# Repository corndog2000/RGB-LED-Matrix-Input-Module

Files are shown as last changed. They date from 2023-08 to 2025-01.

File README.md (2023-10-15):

# RGB-LED-Matrix-Input-Module

# Please check this project's license. It uses a Attribution-NonCommercial-ShareAlike 4.0 International license.

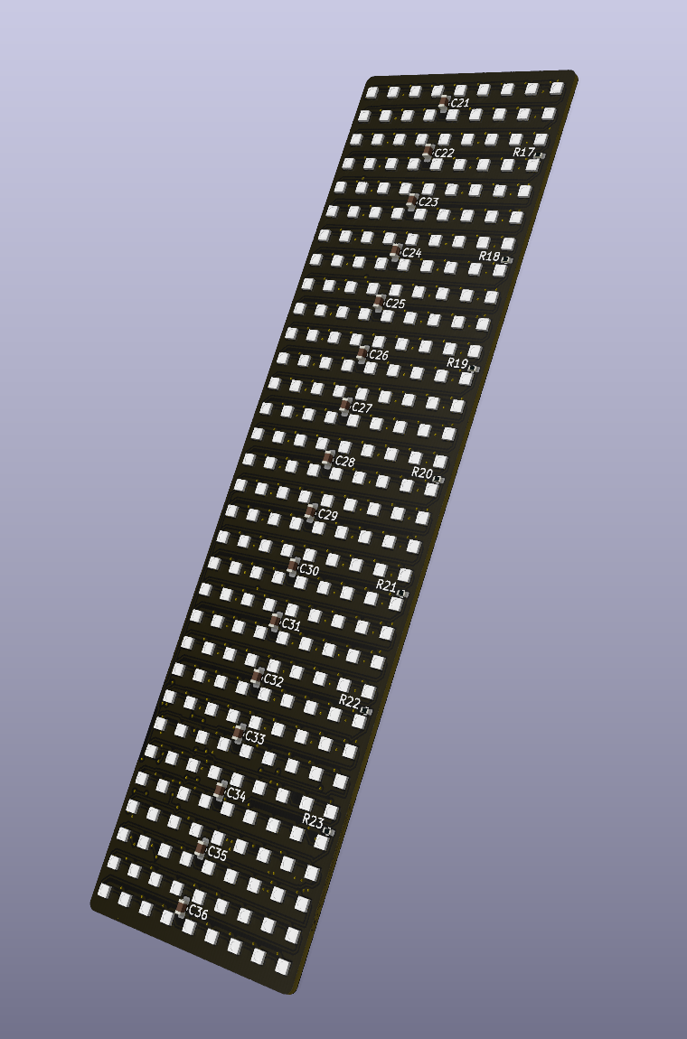
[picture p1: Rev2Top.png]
Rev 2 3D render front

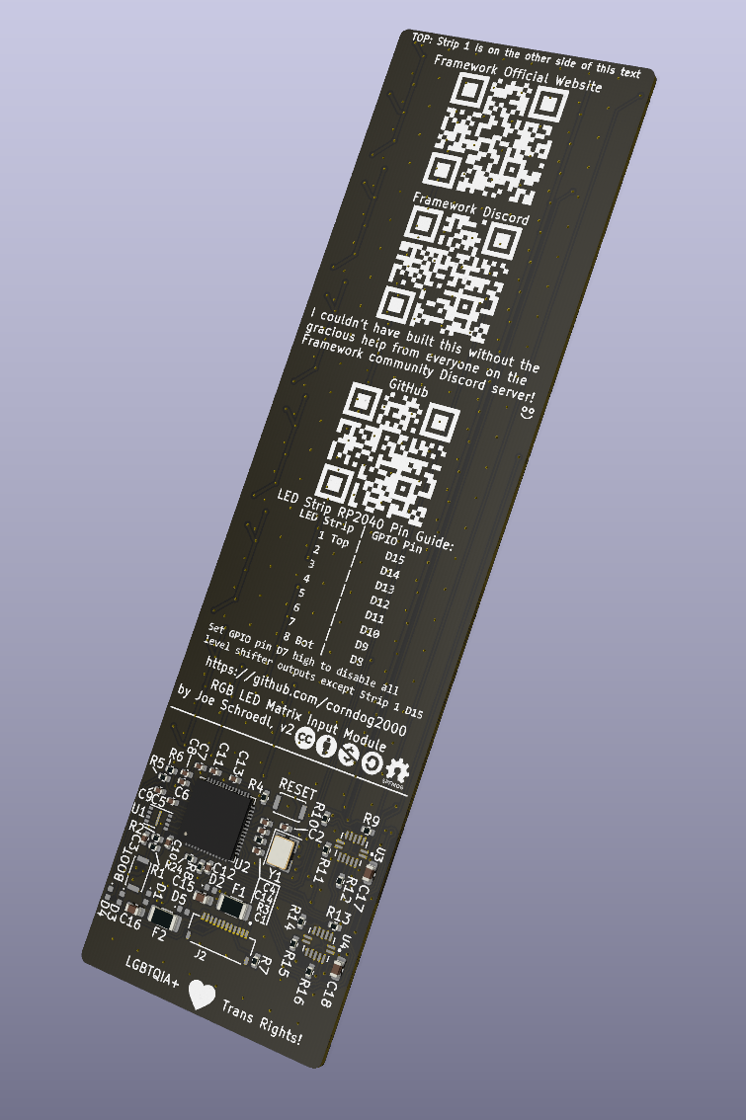
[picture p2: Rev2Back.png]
Rev 2 3D render back


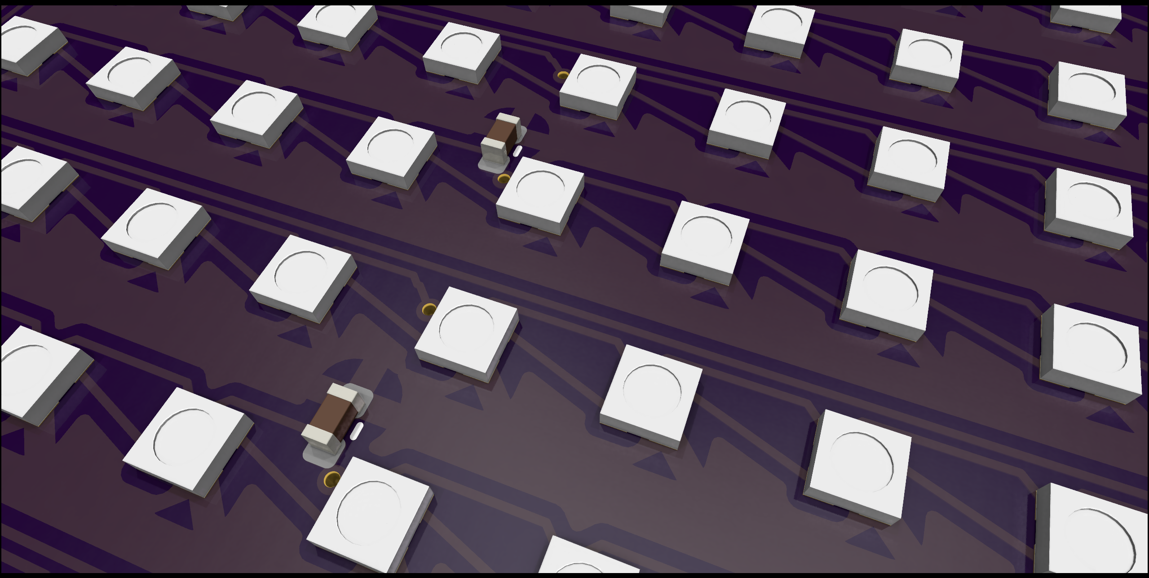
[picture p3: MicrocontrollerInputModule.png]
Close up of the LED Matrix PCB 3D render


Framework Forum Post

Video Demo

Watch the video (https://www.youtube.com/embed/vBwoF8WDbUY)

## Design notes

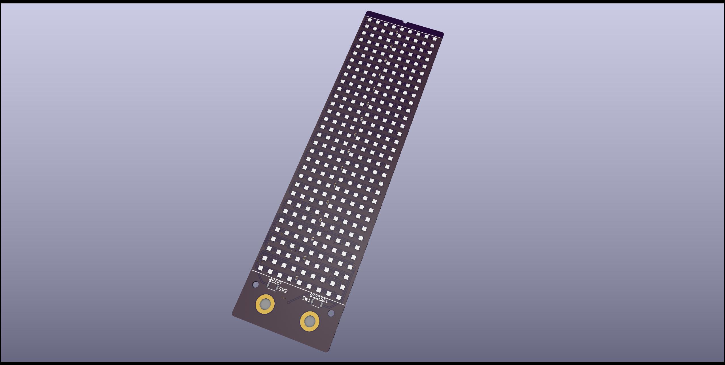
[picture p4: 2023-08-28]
MicrocontrollerInputModule.jpg

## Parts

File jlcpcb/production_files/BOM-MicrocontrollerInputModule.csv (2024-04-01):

Comment | Designator | Footprint | LCSC
1k | R1,R3 | R_0402_1005Metric | C106235
27 | R5,R6 | R_0402_1005Metric | C138021
180k | R7 | R_0402_1005Metric | C138046
100nF | C10,C11,C12,C13,C14,C3,C4,C5,C7,C9 | C_0402_1005Metric | C1525
10uF | C15,C16,C17,C18 | C_0603_1608Metric | C19702
RP2040 | U2 | QFN-56-1EP_7x7mm_P0.4mm_EP3.2x3.2mm | C2040
A6H-2101 | SW1 | SW_A6H-2101_OMR | C224990
470 | R10,R11,R12,R13,R14,R15,R16,R9 | R_0402_1005Metric | C25117
W25Q16JVUXIQ | U1 | SON-8-1EP_3x2mm_P0.5mm_EP0.2x1.6mm | C2843335
SK6805-EC14 | N1,N10,N100,N101,N102,N103,N104,N105,N106,N107,N108,N109,N11,N110,N111,N112,N113,N114,N115,N116,N117,N118,N119,N12,N120,N121,N122,N123,N124,N125,N126,N127,N128,N129,N13,N130,N131,N132,N133,N134,N135,N136,N137,N138,N139,N14,N140,N141,N142,N143,N144,N145,N146,N147,N148,N149,N15,N150,N151,N152,N153,N154,N155,N156,N157,N158,N159,N16,N160,N161,N162,N163,N164,N165,N166,N167,N168,N169,N17,N170,N171,N172,N173,N174,N175,N176,N177,N178,N179,N18,N180,N181,N182,N183,N184,N185,N186,N187,N188,N189,N19,N190,N191,N192,N193,N194,N195,N196,N197,N198,N199,N2,N20,N200,N201,N202,N203,N204,N205,N206,N207,N208,N209,N21,N210,N211,N212,N213,N214,N215,N216,N217,N218,N219,N22,N220,N221,N222,N223,N224,N225,N226,N227,N228,N229,N23,N230,N231,N232,N233,N234,N235,N236,N237,N238,N239,N24,N240,N241,N242,N243,N244,N245,N246,N247,N248,N249,N25,N250,N251,N252,N253,N254,N255,N256,N257,N258,N259,N26,N260,N261,N262,N263,N264,N265,N266,N267,N268,N269,N27,N270,N271,N272,N273,N274,N275,N276,N277,N278,N279,N28,N280,N281,N282,N283,N284,N285,N286,N287,N288,N29,N3,N30,N31,N32,N33,N34,N35,N36,N37,N38,N39,N4,N40,N41,N42,N43,N44,N45,N46,N47,N48,N49,N5,N50,N51,N52,N53,N54,N55,N56,N57,N58,N59,N6,N60,N61,N62,N63,N64,N65,N66,N67,N68,N69,N7,N70,N71,N72,N73,N74,N75,N76,N77,N78,N79,N8,N80,N81,N82,N83,N84,N85,N86,N87,N88,N89,N9,N90,N91,N92,N93,N94,N95,N96,N97,N98,N99 | SK6805-EC14 | C2909055
1uF | C6,C8 | C_0402_1005Metric | C29266
FH34SRJ-12S-0.5SH_50_ | J2 | HRS_FH34SRJ-12S-0.5SH_50_ | C424659
D_TVS | D1,D2,D3,D4,D5 | D_0402_1005Metric | C468904
74AHC125BQ_115 | U3,U4 | QFN50P300X250X100-15N | C554218
10k | R2,R24,R4,R8 | R_0402_1005Metric | C60490
12.000MHz | Y1 | Crystal_SMD_3225-4Pin_3.2x2.5mm | C7294551
15pF | C1,C2 | C_0402_1005Metric | C76950
Polyfuse 600mA | F1 | R_1206_3216Metric | C883122
Polyfuse 200mA | F2 | R_1206_3216Metric | C910826

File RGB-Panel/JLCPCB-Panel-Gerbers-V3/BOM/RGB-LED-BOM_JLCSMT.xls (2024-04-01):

Comment | Designator | Footprint | LCSC Part Number
100nF | C3, C3, C4, C4, C5, C5, C7, C7, C9, C9, C10, C10, C11, C11, C12, C12, C13, C13, C14, C14 | C_0402_1005Metric | C1525
10uF | C15, C15, C16, C16, C17, C17, C18, C18 | C_0603_1608Metric | C19702
15pF | C1, C1, C2, C2 | C_0402_1005Metric | C76950
1uF | C6, C6, C8, C8 | C_0402_1005Metric | C29266
470 Ohm | R9, R9, R10, R10, R11, R11, R12, R12, R13, R13, R14, R14, R15, R15, R16, R16 | R_0402_1005Metric | C25117
10k Ohm | R2, R2, R4, R4, R8, R8, R24, R24 | R_0402_1005Metric | C60490
1k Ohm | R1, R1, R3, R3 | R_0402_1005Metric | C106235
27 Ohm | R5, R5, R6, R6 | R_0402_1005Metric | C138021
180k Ohm | R7, R7 | R_0402_1005Metric | C138046
D_TVS | D1, D1, D2, D2, D3, D3, D4, D4, D5, D5 | D_0402_1005Metric | C468904
74AHC125BQ_115 | U3, U3, U4, U4 | QFN50P300X250X100-15N | C554218
W25Q16JVUXIQ | U1, U1 | SON-8-1EP_3x2mm_P0.5mm_EP0.2x1.6mm | C2843335
RP2040 | U2, U2 | QFN-56-1EP_7x7mm_P0.4mm_EP3.2x3.2mm | C2040
12.000MHz | Y1, Y1 | Crystal_SMD_3225-4Pin_3.2x2.5mm | C7294551
Polyfuse 600mA | F1, F1 | R_1206_3216Metric | C883122
Polyfuse 200mA | F2, F2 | R_1206_3216Metric | C910826
A6H-2101 | SW1, SW1 | SW_A6H-2101_OMR | C224990
SK6805-EC14 | N1, N1, N2, N2, N3, N3, N4, N4, N5, N5, N6, N6, N7, N7, N8, N8, N9, N9, N10, N10, N11, N11, N12, N12, N13, N13, N14, N14, N15, N15, N16, N16, N17, N17, N18, N18, N19, N19, N20, N20, N21, N21, N22, N22, N23, N23, N24, N24, N25, N25, N26, N26, N27, N27, N28, N28, N29, N29, N30, N30, N31, N31, N32, N32, N33, N33, N34, N34, N35, N35, N36, N36, N37, N37, N38, N38, N39, N39, N40, N40, N41, N41, N42, N42, N43, N43, N44, N44, N45, N45, N46, N46, N47, N47, N48, N48, N49, N49, N50, N50, N51, N51, N52, N52, N53, N53, N54, N54, N55, N55, N56, N56, N57, N57, N58, N58, N59, N59, N60, N60, N61, N61, N62, N62, N63, N63, N64, N64, N65, N65, N66, N66, N67, N67, N68, N68, N69, N69, N70, N70, N71, N71, N72, N72, N73, N73, N74, N74, N75, N75, N76, N76, N77, N77, N78, N78, N79, N79, N80, N80, N81, N81, N82, N82, N83, N83, N84, N84, N85, N85, N86, N86, N87, N87, N88, N88, N89, N89, N90, N90, N91, N91, N92, N92, N93, N93, N94, N94, N95, N95, N96, N96, N97, N97, N98, N98, N99, N99, N100, N100, N101, N101, N102, N102, N103, N103, N104, N104, N105, N105, N106, N106, N107, N107, N108, N108, N109, N109, N110, N110, N111, N111, N112, N112, N113, N113, N114, N114, N115, N115, N116, N116, N117, N117, N118, N118, N119, N119, N120, N120, N121, N121, N122, N122, N123, N123, N124, N124, N125, N125, N126, N126, N127, N127, N128, N128, N129, N129, N130, N130, N131, N131, N132, N132, N133, N133, N134, N134, N135, N135, N136, N136, N137, N137, N138, N138, N139, N139, N140, N140, N141, N141, N142, N142, N143, N143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 | SMD,1.4x1.4mm | C2909055
FH34SRJ-12S-0.5SH_50_ | J2, J2 | HRS_FH34SRJ-12S-0.5SH_50_ | C424659
Fiducial | KiKit_FID_B_1 | Fiducial
Fiducial | KiKit_FID_B_2 | Fiducial
Fiducial | KiKit_FID_B_3 | Fiducial
Fiducial | KiKit_FID_B_4 | Fiducial
Fiducial | KiKit_FID_T_1 | Fiducial
Fiducial | KiKit_FID_T_2 | Fiducial
Fiducial | KiKit_FID_T_3 | Fiducial
Fiducial | KiKit_FID_T_4 | Fiducial
NPTH | KiKit_TO_1 | NPTH
NPTH | KiKit_TO_2 | NPTH
NPTH | KiKit_TO_3 | NPTH
NPTH | KiKit_TO_4 | NPTH

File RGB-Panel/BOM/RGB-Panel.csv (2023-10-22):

Id | Designator | Footprint | Quantity | Designation | Supplier and ref
1 | C2,C1,C1,C2 | C_0402_1005Metric | 4 | 15pF
2 | F1,F1 | R_1206_3216Metric | 2 | Polyfuse 600mA
3 | R6,R6,R5,R5 | R_0402_1005Metric | 4 | 27
4 | C5,C9,C11,C9,C11,C10,C7,C4,C14,C13,C3,C12,C12,C4,C10,C7,C14,C13,C3,C5 | C_0402_1005Metric | 20 | 100nF
5 | U4,U3,U4,U3 | QFN50P300X250X100-15N | 4 | 74AHC125BQ_115
6 | R7,R7 | R_0402_1005Metric | 2 | 180k
7 | D5,D2,D2,D4,D1,D3,D3,D5,D1,D4 | D_0402_1005Metric | 10 | D_TVS
8 | C15,C18,C17,C16,C16,C15,C18,C17,C26,C33,C35,C22,C32,C24,C30,C34,C21,C28,C27,C29,C30,C23,C36,C34,C22,C25,C23,C31,C29,C24,C35,C26,C28,C32,C21,C27,C36,C25,C31,C33 | C_0603_1608Metric | 40 | 10uF
9 | KiKit_FID_B_2,KiKit_FID_B_1,KiKit_FID_B_3,KiKit_FID_B_4,KiKit_FID_T_3,KiKit_FID_T_1,KiKit_FID_T_2,KiKit_FID_T_4 | Fiducial | 8 | Fiducial
10 | SW1,SW1 | SW_A6H-2101_OMR | 2 | A6H-2101
11 | C8,C6,C6,C8 | C_0402_1005Metric | 4 | 1uF
12 | Y1,Y1 | Crystal_SMD_3225-4Pin_3.2x2.5mm | 2 | 12.000MHz
13 | F2,F2 | R_1206_3216Metric | 2 | Polyfuse 200mA
14 | U2,U2 | QFN-56-1EP_7x7mm_P0.4mm_EP3.2x3.2mm | 2 | RP2040
15 | J2,J2 | HRS_FH34SRJ-12S-0.5SH_50_ | 2 | FH34SRJ-12S-0.5SH_50_
16 | R3,R3,R1,R1 | R_0402_1005Metric | 4 | 1k
17 | U1,U1 | SON-8-1EP_3x2mm_P0.5mm_EP0.2x1.6mm | 2 | W25Q16JVUXIQ
18 | N121,N31,N122,N137,N257,N236,N151,N4,N38,N98,N156,N68,N286,N81,N83,N28,N120,N67,N141,N149,N273,N259,N128,N219,N59,N172,N261,N127,N49,N51,N223,N40,N58,N181,N210,N52,N268,N119,N280,N85,N154,N54,N120,N65,N210,N50,N110,N235,N284,N109,N165,N254,N78,N271,N193,N132,N69,N267,N190,N216,N257,N248,N54,N21,N7,N1,N188,N224,N248,N3,N247,N221,N126,N57,N72,N148,N195,N272,N31,N17,N169,N115,N274,N113,N194,N203,N256,N92,N91,N14,N251,N220,N89,N95,N100,N253,N110,N104,N19,N146,N131,N260,N232,N247,N228,N80,N215,N2,N77,N3,N189,N259,N25,N212,N96,N41,N246,N21,N151,N180,N156,N102,N9,N202,N287,N9,N53,N232,N265,N103,N105,N75,N262,N158,N106,N174,N240,N246,N233,N119,N233,N271,N264,N252,N160,N118,N55,N124,N36,N212,N13,N145,N47,N111,N244,N26,N276,N66,N136,N61,N51,N220,N45,N164,N187,N126,N27,N107,N186,N278,N114,N189,N153,N33,N221,N8,N273,N135,N181,N199,N173,N14,N88,N92,N176,N178,N71,N144,N200,N207,N191,N125,N280,N20,N227,N215,N216,N254,N108,N266,N32,N60,N150,N162,N168,N93,N159,N95,N197,N88,N79,N22,N186,N38,N90,N285,N223,N242,N104,N281,N39,N7,N93,N30,N103,N238,N237,N40,N67,N90,N185,N24,N238,N282,N143,N72,N79,N179,N227,N191,N5,N146,N214,N263,N243,N264,N239,N117,N171,N124,N276,N184,N22,N89,N161,N147,N15,N243,N169,N148,N91,N99,N116,N59,N76,N206,N263,N10,N27,N207,N36,N144,N145,N106,N63,N64,N222,N139,N60,N226,N47,N204,N205,N163,N269,N43,N287,N278,N64,N112,N43,N244,N234,N153,N174,N84,N44,N108,N11,N185,N99,N44,N5,N149,N190,N283,N134,N48,N63,N270,N198,N35,N118,N231,N48,N245,N42,N139,N25,N33,N155,N177,N133,N52,N46,N2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 | SK6805-EC14 | 576 | ~
19 | KiKit_MB_41_1,KiKit_MB_15_4,KiKit_MB_48_5,KiKit_MB_2_4,KiKit_MB_38_4,KiKit_MB_48_4,KiKit_MB_10_1,KiKit_MB_46_1,KiKit_MB_20_1,KiKit_MB_41_2,KiKit_MB_21_3,KiKit_MB_45_6,KiKit_MB_10_2,KiKit_MB_8_1,KiKit_MB_9_1,KiKit_MB_36_4,KiKit_MB_46_4,KiKit_MB_30_1,KiKit_MB_9_3,KiKit_MB_42_2,KiKit_MB_28_1,KiKit_MB_24_3,KiKit_MB_14_2,KiKit_TO_2,KiKit_MB_27_2,KiKit_MB_30_3,KiKit_MB_23_4,KiKit_MB_35_2,KiKit_MB_33_4,KiKit_MB_37_1,KiKit_MB_46_3,KiKit_MB_42_3,KiKit_MB_40_4,KiKit_MB_33_3,KiKit_MB_28_3,KiKit_MB_44_6,KiKit_MB_48_1,KiKit_MB_32_3,KiKit_MB_13_2,KiKit_MB_27_3,KiKit_MB_11_4,KiKit_MB_44_4,KiKit_MB_48_7,KiKit_MB_42_4,KiKit_TO_1,KiKit_MB_9_4,KiKit_MB_26_2,KiKit_MB_48_3,KiKit_MB_24_2,KiKit_MB_5_2,KiKit_MB_18_3,KiKit_MB_41_3,KiKit_MB_44_5,KiKit_MB_41_5,KiKit_MB_18_4,KiKit_MB_29_4,KiKit_MB_4_1,KiKit_MB_47_5,KiKit_MB_1_4,KiKit_MB_43_4,KiKit_MB_31_3,KiKit_MB_25_3,KiKit_MB_2_2,KiKit_MB_10_4,KiKit_MB_16_1,KiKit_MB_35_3,KiKit_MB_44_3,KiKit_MB_1_2,KiKit_MB_12_3,KiKit_MB_44_7,KiKit_MB_43_2,KiKit_MB_33_1,KiKit_MB_31_2,KiKit_TO_4,KiKit_MB_8_3,KiKit_MB_17_3,KiKit_MB_17_4,KiKit_MB_47_6,KiKit_MB_13_3,KiKit_MB_28_2,KiKit_MB_14_3,KiKit_MB_21_2,KiKit_MB_38_3,KiKit_MB_7_3,KiKit_MB_4_4,KiKit_MB_23_1,KiKit_MB_27_4,KiKit_MB_4_2,KiKit_MB_17_1,KiKit_MB_15_3,KiKit_MB_25_4,KiKit_MB_18_2,KiKit_MB_27_1,KiKit_MB_24_4,KiKit_TO_3,KiKit_MB_14_4,KiKit_MB_37_3,KiKit_MB_46_6,KiKit_MB_47_4,KiKit_MB_3_4,KiKit_MB_20_2,KiKit_MB_46_2,KiKit_MB_14_1,KiKit_MB_42_1,KiKit_MB_22_1,KiKit_MB_39_2,KiKit_MB_31_1,KiKit_MB_30_4,KiKit_MB_42_7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 | NPTH | 220 | NPTH

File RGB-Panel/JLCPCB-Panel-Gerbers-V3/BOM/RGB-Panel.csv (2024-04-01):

Id | Designator | Footprint | Quantity | Designation | Supplier and ref
1 | C15,C15,C16,C17,C18,C16,C17,C18 | C_0603_1608Metric | 8 | 10uF
2 | Y1,Y1 | Crystal_SMD_3225-4Pin_3.2x2.5mm | 2 | 12.000MHz
3 | U4,U4,U3,U3 | QFN50P300X250X100-15N | 4 | 74AHC125BQ_115
4 | F2,F2 | R_1206_3216Metric | 2 | Polyfuse 200mA
5 | R1,R3,R1,R3 | R_0402_1005Metric | 4 | 1k
6 | D2,D1,D3,D2,D3,D5,D4,D4,D1,D5 | D_0402_1005Metric | 10 | D_TVS
7 | R7,R7 | R_0402_1005Metric | 2 | 180k
8 | SW1,SW1 | SW_A6H-2101_OMR | 2 | A6H-2101
9 | J2,J2 | HRS_FH34SRJ-12S-0.5SH_50_ | 2 | FH34SRJ-12S-0.5SH_50_
10 | R5,R6,R6,R5 | R_0402_1005Metric | 4 | 27
11 | C5,C5,C10,C7,C9,C13,C12,C12,C9,C14,C11,C10,C13,C3,C7,C4,C14,C11,C3,C4 | C_0402_1005Metric | 20 | 100nF
12 | C1,C2,C1,C2 | C_0402_1005Metric | 4 | 15pF
13 | U1,U1 | SON-8-1EP_3x2mm_P0.5mm_EP0.2x1.6mm | 2 | W25Q16JVUXIQ
14 | C6,C8,C6,C8 | C_0402_1005Metric | 4 | 1uF
15 | KiKit_FID_B_4,KiKit_FID_B_2,KiKit_FID_B_1,KiKit_FID_B_3,KiKit_FID_T_3,KiKit_FID_T_1,KiKit_FID_T_2,KiKit_FID_T_4 | Fiducial | 8 | Fiducial
16 | U2,U2 | QFN-56-1EP_7x7mm_P0.4mm_EP3.2x3.2mm | 2 | RP2040
17 | F1,F1 | R_1206_3216Metric | 2 | Polyfuse 600mA
18 | N13,N117,N168,N184,N66,N53,N282,N68,N104,N122,N273,N173,N41,N72,N153,N175,N255,N138,N174,N240,N180,N16,N7,N96,N148,N260,N83,N267,N132,N280,N144,N225,N240,N205,N267,N101,N139,N160,N179,N112,N48,N154,N231,N65,N189,N95,N180,N29,N81,N182,N47,N105,N40,N243,N213,N150,N162,N253,N221,N206,N26,N216,N27,N131,N222,N184,N6,N189,N142,N248,N31,N3,N121,N132,N210,N272,N18,N127,N55,N268,N108,N164,N145,N46,N10,N258,N60,N61,N52,N115,N34,N61,N230,N276,N123,N185,N116,N212,N90,N252,N64,N204,N251,N157,N113,N34,N123,N54,N268,N191,N133,N278,N274,N182,N50,N70,N226,N44,N69,N41,N30,N54,N24,N8,N114,N168,N279,N266,N165,N170,N247,N32,N279,N262,N239,N43,N125,N181,N214,N152,N262,N178,N159,N203,N28,N11,N235,N201,N163,N49,N190,N110,N71,N176,N217,N26,N45,N242,N143,N80,N225,N144,N43,N274,N9,N64,N195,N158,N69,N161,N211,N70,N232,N51,N15,N71,N93,N82,N120,N214,N66,N103,N140,N48,N44,N129,N85,N102,N50,N62,N241,N120,N63,N244,N137,N87,N271,N228,N227,N33,N222,N85,N231,N73,N1,N39,N107,N57,N210,N215,N36,N79,N93,N197,N254,N94,N248,N152,N237,N94,N20,N117,N55,N108,N223,N8,N237,N19,N136,N30,N247,N192,N273,N206,N266,N217,N89,N218,N83,N130,N285,N286,N77,N128,N232,N146,N167,N242,N12,N196,N167,N275,N88,N235,N177,N5,N19,N158,N5,N198,N106,N11,N134,N99,N35,N183,N2,N81,N288,N124,N97,N116,N211,N88,N74,N56,N99,N89,N245,N233,N126,N105,N103,N234,N86,N269,N141,N286,N21,N166,N73,N22,N104,N134,N151,N265,N141,N124,N218,N205,N219,N159,N233,N145,N257,N118,N252,N146,N58,N59,N52,N245,N13,N4,N169,N118,N51,N97,N40,N229,N181,N156,N276,N202,N14,N18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 | SK6805-EC14 | 576 | ~
19 | KiKit_MB_13_3,KiKit_MB_31_3,KiKit_MB_15_4,KiKit_MB_38_2,KiKit_MB_19_4,KiKit_MB_40_1,KiKit_MB_47_6,KiKit_MB_39_1,KiKit_MB_8_3,KiKit_MB_4_1,KiKit_MB_8_1,KiKit_MB_21_3,KiKit_MB_40_2,KiKit_MB_43_2,KiKit_MB_41_4,KiKit_MB_9_1,KiKit_MB_43_6,KiKit_MB_4_4,KiKit_MB_12_2,KiKit_MB_44_2,KiKit_TO_1,KiKit_MB_15_3,KiKit_MB_1_3,KiKit_MB_25_3,KiKit_MB_12_1,KiKit_MB_25_1,KiKit_MB_32_2,KiKit_MB_34_1,KiKit_MB_28_2,KiKit_MB_14_1,KiKit_MB_11_4,KiKit_MB_43_4,KiKit_MB_6_4,KiKit_MB_3_3,KiKit_MB_19_1,KiKit_MB_7_1,KiKit_MB_5_1,KiKit_MB_12_4,KiKit_MB_48_6,KiKit_MB_6_3,KiKit_MB_3_4,KiKit_MB_1_4,KiKit_MB_30_2,KiKit_MB_5_4,KiKit_MB_46_1,KiKit_MB_24_3,KiKit_MB_45_3,KiKit_MB_40_3,KiKit_MB_7_2,KiKit_MB_8_4,KiKit_MB_22_1,KiKit_MB_9_3,KiKit_MB_41_2,KiKit_MB_17_1,KiKit_MB_46_7,KiKit_MB_35_1,KiKit_MB_48_1,KiKit_MB_27_2,KiKit_MB_17_3,KiKit_MB_43_3,KiKit_MB_18_4,KiKit_MB_36_3,KiKit_MB_43_1,KiKit_MB_7_4,KiKit_MB_27_1,KiKit_MB_16_4,KiKit_MB_35_3,KiKit_MB_48_3,KiKit_MB_39_2,KiKit_MB_43_5,KiKit_MB_10_4,KiKit_MB_21_2,KiKit_MB_44_6,KiKit_MB_1_1,KiKit_MB_22_3,KiKit_MB_10_1,KiKit_MB_37_1,KiKit_MB_36_2,KiKit_MB_34_4,KiKit_MB_3_1,KiKit_MB_28_4,KiKit_MB_31_2,KiKit_MB_26_1,KiKit_MB_31_4,KiKit_MB_17_4,KiKit_MB_23_2,KiKit_MB_47_7,KiKit_MB_38_1,KiKit_MB_22_2,KiKit_MB_2_4,KiKit_MB_29_2,KiKit_MB_36_1,KiKit_MB_19_2,KiKit_MB_5_3,KiKit_MB_30_1,KiKit_MB_9_4,KiKit_MB_4_3,KiKit_MB_17_2,KiKit_MB_11_3,KiKit_MB_18_2,KiKit_MB_46_6,KiKit_MB_2_2,KiKit_MB_41_3,KiKit_MB_26_2,KiKit_MB_43_7,KiKit_MB_36_4,KiKit_MB_37_2,KiKit_MB_29_3,KiKit_MB_42_2,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 | NPTH | 220 | NPTH
20 | ,,,,, |  | 6

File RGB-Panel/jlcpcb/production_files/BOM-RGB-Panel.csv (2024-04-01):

Comment | Designator | Footprint | LCSC
1k | R1-0,R1-1,R3-0,R3-1 | R_0402_1005Metric | C106235
27 | R5-0,R5-1,R6-0,R6-1 | R_0402_1005Metric | C138021
180k | R7-0,R7-1 | R_0402_1005Metric | C138046
100nF | C10-0,C10-1,C11-0,C11-1,C12-0,C12-1,C13-0,C13-1,C14-0,C14-1,C3-0,C3-1,C4-0,C4-1,C5-0,C5-1,C7-0,C7-1,C9-0,C9-1 | C_0402_1005Metric | C1525
10uF | C15-0,C15-1,C16-0,C16-1,C17-0,C17-1,C18-0,C18-1 | C_0603_1608Metric | C19702
RP2040 | U2-0,U2-1 | QFN-56-1EP_7x7mm_P0.4mm_EP3.2x3.2mm | C2040
A6H-2101 | SW1-0,SW1-1 | SW_A6H-2101_OMR | C224990
470 | R10-0,R10-1,R11-0,R11-1,R12-0,R12-1,R13-0,R13-1,R14-0,R14-1,R15-0,R15-1,R16-0,R16-1,R9-0,R9-1 | R_0402_1005Metric | C25117
W25Q16JVUXIQ | U1-0,U1-1 | SON-8-1EP_3x2mm_P0.5mm_EP0.2x1.6mm | C2843335
SK6805-EC14 | N1-0,N1-1,N10-0,N10-1,N100-0,N100-1,N101-0,N101-1,N102-0,N102-1,N103-0,N103-1,N104-0,N104-1,N105-0,N105-1,N106-0,N106-1,N107-0,N107-1,N108-0,N108-1,N109-0,N109-1,N11-0,N11-1,N110-0,N110-1,N111-0,N111-1,N112-0,N112-1,N113-0,N113-1,N114-0,N114-1,N115-0,N115-1,N116-0,N116-1,N117-0,N117-1,N118-0,N118-1,N119-0,N119-1,N12-0,N12-1,N120-0,N120-1,N121-0,N121-1,N122-0,N122-1,N123-0,N123-1,N124-0,N124-1,N125-0,N125-1,N126-0,N126-1,N127-0,N127-1,N128-0,N128-1,N129-0,N129-1,N13-0,N13-1,N130-0,N130-1,N131-0,N131-1,N132-0,N132-1,N133-0,N133-1,N134-0,N134-1,N135-0,N135-1,N136-0,N136-1,N137-0,N137-1,N138-0,N138-1,N139-0,N139-1,N14-0,N14-1,N140-0,N140-1,N141-0,N141-1,N142-0,N142-1,N143-0,N143-1,N144-0,N144-1,N145-0,N145-1,N146-0,N146-1,N147-0,N147-1,N148-0,N148-1,N149-0,N149-1,N15-0,N15-1,N150-0,N150-1,N151-0,N151-1,N152-0,N152-1,N153-0,N153-1,N154-0,N154-1,N155-0,N155-1,N156-0,N156-1,N157-0,N157-1,N158-0,N158-1,N159-0,N159-1,N16-0,N16-1,N160-0,N160-1,N161-0,N161-1,N162-0,N162-1,N163-0,N163-1,N164-0,N164-1,N165-0,N165-1,N166-0,N166-1,N167-0,N167-1,N168-0,N168-1,N169-0,N169-1,N17-0,N17-1,N170-0,N170-1,N171-0,N171-1,N172-0,N172-1,N173-0,N173-1,N174-0,N174-1,N175-0,N175-1,N176-0,N176-1,N177-0,N177-1,N178-0,N178-1,N179-0,N179-1,N18-0,N18-1,N180-0,N180-1,N181-0,N181-1,N182-0,N182-1,N183-0,N183-1,N184-0,N184-1,N185-0,N185-1,N186-0,N186-1,N187-0,N187-1,N188-0,N188-1,N189-0,N189-1,N19-0,N19-1,N190-0,N190-1,N191-0,N191-1,N192-0,N192-1,N193-0,N193-1,N194-0,N194-1,N195-0,N195-1,N196-0,N196-1,N197-0,N19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 | SK6805-EC14 | C2909055
1uF | C6-0,C6-1,C8-0,C8-1 | C_0402_1005Metric | C29266
FH34SRJ-12S-0.5SH_50_ | J2-0,J2-1 | HRS_FH34SRJ-12S-0.5SH_50_ | C424659
D_TVS | D1-0,D1-1,D2-0,D2-1,D3-0,D3-1,D4-0,D4-1,D5-0,D5-1 | D_0402_1005Metric | C468904
74AHC125BQ_115 | U3-0,U3-1,U4-0,U4-1 | QFN50P300X250X100-15N | C554218
10k | R2-0,R2-1,R24-0,R24-1,R4-0,R4-1,R8-0,R8-1 | R_0402_1005Metric | C60490
12.000MHz | Y1-0,Y1-1 | Crystal_SMD_3225-4Pin_3.2x2.5mm | C7294551
15pF | C1-0,C1-1,C2-0,C2-1 | C_0402_1005Metric | C76950
Polyfuse 600mA | F1-0,F1-1 | R_1206_3216Metric | C883122
Polyfuse 200mA | F2-0,F2-1 | R_1206_3216Metric | C910826
Fiducial | KiKit_FID_B_4 | Fiducial
Fiducial | KiKit_FID_B_2 | Fiducial
Fiducial | KiKit_FID_B_3 | Fiducial
Fiducial | KiKit_FID_B_1 | Fiducial
NPTH | KiKit_MB_48_6 | NPTH
NPTH | KiKit_MB_32_2 | NPTH
NPTH | KiKit_MB_34_2 | NPTH
NPTH | KiKit_MB_27_2 | NPTH
NPTH | KiKit_MB_39_2 | NPTH
NPTH | KiKit_MB_46_7 | NPTH
NPTH | KiKit_MB_34_4 | NPTH
NPTH | KiKit_MB_37_4 | NPTH
NPTH | KiKit_MB_25_1 | NPTH
NPTH | KiKit_MB_45_5 | NPTH
NPTH | KiKit_MB_38_4 | NPTH
NPTH | KiKit_MB_41_1 | NPTH
NPTH | KiKit_MB_36_1 | NPTH
NPTH | KiKit_MB_33_4 | NPTH
NPTH | KiKit_MB_48_2 | NPTH
NPTH | KiKit_MB_12_4 | NPTH
Fiducial | KiKit_FID_T_3 | Fiducial
NPTH | KiKit_MB_25_4 | NPTH
NPTH | KiKit_MB_40_4 | NPTH
NPTH | KiKit_MB_48_7 | NPTH
NPTH | KiKit_MB_23_2 | NPTH
NPTH | KiKit_MB_21_2 | NPTH
NPTH | KiKit_MB_5_4 | NPTH
NPTH | KiKit_TO_3 | NPTH
NPTH | KiKit_MB_9_3 | NPTH
NPTH | KiKit_MB_3_1 | NPTH
NPTH | KiKit_MB_36_3 | NPTH
NPTH | KiKit_MB_21_1 | NPTH
NPTH | KiKit_MB_43_3 | NPTH
NPTH | KiKit_MB_41_3 | NPTH
NPTH | KiKit_MB_14_3 | NPTH
NPTH | KiKit_MB_16_2 | NPTH
NPTH | KiKit_MB_20_1 | NPTH
NPTH | KiKit_MB_29_2 | NPTH
NPTH | KiKit_MB_17_2 | NPTH
NPTH | KiKit_MB_38_2 | NPTH
NPTH | KiKit_MB_10_1 | NPTH
NPTH | KiKit_MB_47_4 | NPTH
NPTH | KiKit_MB_45_7 | NPTH
NPTH | KiKit_MB_46_5 | NPTH
NPTH | KiKit_MB_4_3 | NPTH
NPTH | KiKit_MB_23_4 | NPTH
NPTH | KiKit_MB_23_1 | NPTH
NPTH | KiKit_MB_8_1 | NPTH
NPTH | KiKit_MB_39_3 | NPTH
NPTH | KiKit_MB_42_2 | NPTH
NPTH | KiKit_MB_5_3 | NPTH
NPTH | KiKit_MB_42_4 | NPTH
NPTH | KiKit_MB_43_4 | NPTH
Fiducial | KiKit_FID_T_1 | Fiducial
NPTH | KiKit_MB_24_3 | NPTH
NPTH | KiKit_MB_14_4 | NPTH
NPTH | KiKit_MB_25_3 | NPTH
NPTH | KiKit_MB_46_2 | NPTH
NPTH | KiKit_MB_26_1 | NPTH
NPTH | KiKit_MB_5_1 | NPTH
NPTH | KiKit_MB_4_4 | NPTH
NPTH | KiKit_MB_7_1 | NPTH
NPTH | KiKit_MB_44_3 | NPTH
NPTH | KiKit_MB_31_2 | NPTH
NPTH | KiKit_MB_31_1 | NPTH
NPTH | KiKit_MB_27_3 | NPTH
NPTH | KiKit_MB_10_3 | NPTH
NPTH | KiKit_MB_4_2 | NPTH
NPTH | KiKit_MB_19_1 | NPTH
NPTH | KiKit_MB_12_2 | NPTH
NPTH | KiKit_MB_13_1 | NPTH
NPTH | KiKit_MB_3_4 | NPTH
NPTH | KiKit_MB_23_3 | NPTH
NPTH | KiKit_MB_48_4 | NPTH
NPTH | KiKit_MB_47_1 | NPTH
NPTH | KiKit_MB_35_3 | NPTH
NPTH | KiKit_MB_38_1 | NPTH
NPTH | KiKit_MB_34_1 | NPTH
NPTH | KiKit_MB_24_1 | NPTH
NPTH | KiKit_MB_44_1 | NPTH
NPTH | KiKit_TO_1 | NPTH
NPTH | KiKit_MB_20_2 | NPTH
NPTH | KiKit_MB_47_2 | NPTH
NPTH | KiKit_MB_10_4 | NPTH
NPTH | KiKit_MB_24_2 | NPTH
NPTH | KiKit_MB_6_2 | NPTH
NPTH | KiKit_MB_28_2 | NPTH
NPTH | KiKit_MB_41_5 | NPTH
NPTH | KiKit_MB_11_3 | NPTH
NPTH | KiKit_MB_32_3 | NPTH
NPTH | KiKit_MB_42_3 | NPTH
NPTH | KiKit_MB_28_4 | NPTH
NPTH | KiKit_MB_15_4 | NPTH
NPTH | KiKit_MB_41_4 | NPTH
NPTH | KiKit_MB_37_3 | NPTH
NPTH | KiKit_MB_29_1 | NPTH
NPTH | KiKit_MB_17_1 | NPTH
NPTH | KiKit_MB_12_3 | NPTH
NPTH | KiKit_MB_45_6 | NPTH
NPTH | KiKit_MB_43_6 | NPTH
NPTH | KiKit_MB_15_1 | NPTH
NPTH | KiKit_MB_47_6 | NPTH
NPTH | KiKit_MB_45_2 | NPTH
NPTH | KiKit_MB_1_4 | NPTH
NPTH | KiKit_MB_7_4 | NPTH
NPTH | KiKit_MB_47_5 | NPTH
NPTH | KiKit_MB_31_3 | NPTH
NPTH | KiKit_MB_26_2 | NPTH
NPTH | KiKit_MB_26_3 | NPTH
NPTH | KiKit_MB_3_3 | NPTH
NPTH | KiKit_MB_2_4 | NPTH
NPTH | KiKit_MB_35_4 | NPTH
NPTH | KiKit_MB_42_1 | NPTH
NPTH | KiKit_MB_44_2 | NPTH
NPTH | KiKit_MB_9_4 | NPTH
NPTH | KiKit_MB_10_2 | NPTH
NPTH | KiKit_MB_42_7 | NPTH
NPTH | KiKit_MB_18_1 | NPTH
NPTH | KiKit_MB_31_4 | NPTH
NPTH | KiKit_MB_7_3 | NPTH
NPTH | KiKit_TO_2 | NPTH
NPTH | KiKit_MB_47_7 | NPTH
NPTH | KiKit_MB_43_2 | NPTH
NPTH | KiKit_MB_43_7 | NPTH
NPTH | KiKit_MB_29_4 | NPTH
NPTH | KiKit_MB_3_2 | NPTH
NPTH | KiKit_MB_35_2 | NPTH
NPTH | KiKit_MB_18_2 | NPTH
NPTH | KiKit_MB_26_4 | NPTH
NPTH | KiKit_MB_39_1 | NPTH
NPTH | KiKit_MB_35_1 | NPTH
NPTH | KiKit_MB_33_1 | NPTH
NPTH | KiKit_MB_41_2 | NPTH
NPTH | KiKit_MB_29_3 | NPTH
NPTH | KiKit_MB_40_1 | NPTH
NPTH | KiKit_MB_40_2 | NPTH
NPTH | KiKit_MB_28_3 | NPTH
NPTH | KiKit_MB_1_3 | NPTH
NPTH | KiKit_MB_33_3 | NPTH
NPTH | KiKit_MB_2_3 | NPTH
NPTH | KiKit_MB_22_4 | NPTH
NPTH | KiKit_MB_30_3 | NPTH
NPTH | KiKit_MB_44_4 | NPTH
NPTH | KiKit_MB_8_4 | NPTH
Fiducial | KiKit_FID_T_4 | Fiducial
NPTH | KiKit_MB_14_2 | NPTH
NPTH | KiKit_MB_47_3 | NPTH
NPTH | KiKit_MB_42_6 | NPTH
NPTH | KiKit_MB_16_3 | NPTH
NPTH | KiKit_MB_44_7 | NPTH
NPTH | KiKit_MB_16_1 | NPTH
NPTH | KiKit_MB_24_4 | NPTH
NPTH | KiKit_MB_36_2 | NPTH
NPTH | KiKit_MB_46_4 | NPTH
NPTH | KiKit_MB_17_4 | NPTH
NPTH | KiKit_MB_13_2 | NPTH
NPTH | KiKit_MB_30_4 | NPTH
NPTH | KiKit_MB_30_2 | NPTH
NPTH | KiKit_MB_9_2 | NPTH
NPTH | KiKit_MB_2_2 | NPTH
NPTH | KiKit_MB_11_2 | NPTH
NPTH | KiKit_TO_4 | NPTH
NPTH | KiKit_MB_13_3 | NPTH
NPTH | KiKit_MB_27_4 | NPTH
NPTH | KiKit_MB_22_3 | NPTH
NPTH | KiKit_MB_30_1 | NPTH
Fiducial | KiKit_FID_T_2 | Fiducial
NPTH | KiKit_MB_6_4 | NPTH
NPTH | KiKit_MB_20_4 | NPTH
NPTH | KiKit_MB_19_3 | NPTH
NPTH | KiKit_MB_19_4 | NPTH
NPTH | KiKit_MB_1_2 | NPTH
NPTH | KiKit_MB_21_3 | NPTH
NPTH | KiKit_MB_37_2 | NPTH
NPTH | KiKit_MB_18_3 | NPTH
NPTH | KiKit_MB_19_2 | NPTH
NPTH | KiKit_MB_6_3 | NPTH
NPTH | KiKit_MB_48_1 | NPTH
NPTH | KiKit_MB_43_1 | NPTH
NPTH | KiKit_MB_8_3 | NPTH
NPTH | KiKit_MB_43_5 | NPTH
NPTH | KiKit_MB_39_4 | NPTH
NPTH | KiKit_MB_11_4 | NPTH
NPTH | KiKit_MB_41_7 | NPTH
NPTH | KiKit_MB_14_1 | NPTH
NPTH | KiKit_MB_17_3 | NPTH
NPTH | KiKit_MB_32_1 | NPTH
NPTH | KiKit_MB_16_4 | NPTH
NPTH | KiKit_MB_28_1 | NPTH
NPTH | KiKit_MB_15_2 | NPTH
NPTH | KiKit_MB_42_5 | NPTH
NPTH | KiKit_MB_36_4 | NPTH
NPTH | KiKit_MB_21_4 | NPTH
NPTH | KiKit_MB_32_4 | NPTH
NPTH | KiKit_MB_6_1 | NPTH
NPTH | KiKit_MB_8_2 | NPTH
NPTH | KiKit_MB_46_6 | NPTH
NPTH | KiKit_MB_37_1 | NPTH
NPTH | KiKit_MB_20_3 | NPTH
NPTH | KiKit_MB_45_4 | NPTH
NPTH | KiKit_MB_48_5 | NPTH
NPTH | KiKit_MB_1_1 | NPTH
NPTH | KiKit_MB_27_1 | NPTH
NPTH | KiKit_MB_2_1 | NPTH
NPTH | KiKit_MB_11_1 | NPTH
NPTH | KiKit_MB_5_2 | NPTH
NPTH | KiKit_MB_9_1 | NPTH
NPTH | KiKit_MB_46_3 | NPTH
NPTH | KiKit_MB_34_3 | NPTH
NPTH | KiKit_MB_38_3 | NPTH
NPTH | KiKit_MB_22_1 | NPTH
NPTH | KiKit_MB_15_3 | NPTH
NPTH | KiKit_MB_25_2 | NPTH
NPTH | KiKit_MB_13_4 | NPTH
NPTH | KiKit_MB_48_3 | NPTH
NPTH | KiKit_MB_22_2 | NPTH
NPTH | KiKit_MB_40_3 | NPTH
NPTH | KiKit_MB_12_1 | NPTH
NPTH | KiKit_MB_41_6 | NPTH
NPTH | KiKit_MB_44_5 | NPTH
NPTH | KiKit_MB_4_1 | NPTH
NPTH | KiKit_MB_45_1 | NPTH
NPTH | KiKit_MB_46_1 | NPTH
NPTH | KiKit_MB_44_6 | NPTH
NPTH | KiKit_MB_18_4 | NPTH
NPTH | KiKit_MB_45_3 | NPTH
NPTH | KiKit_MB_33_2 | NPTH
NPTH | KiKit_MB_7_2 | NPTH

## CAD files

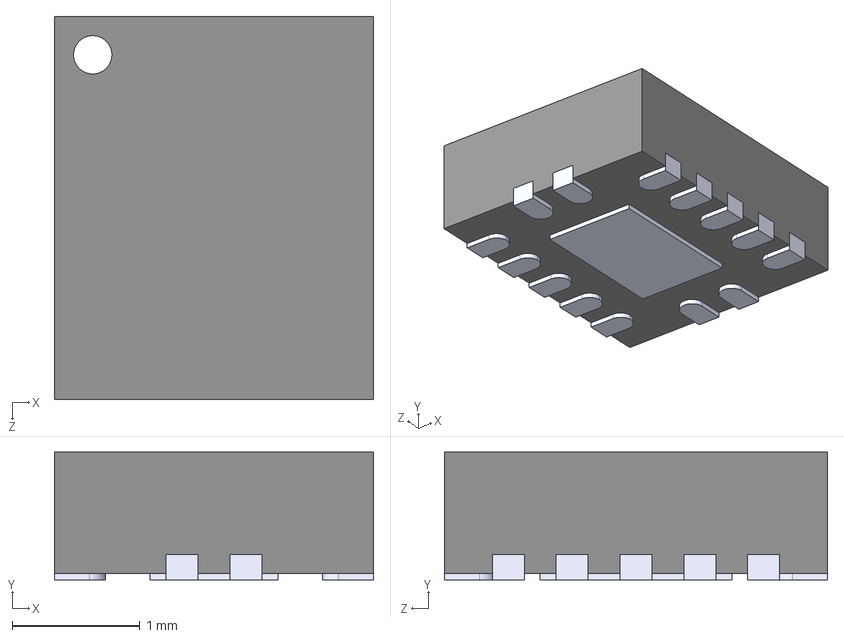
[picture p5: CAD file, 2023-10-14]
Footprint Downloads/74AHC125BQ_115/74AHC125BQ_115.step
2.50 x 1.00 x 3.00 mm

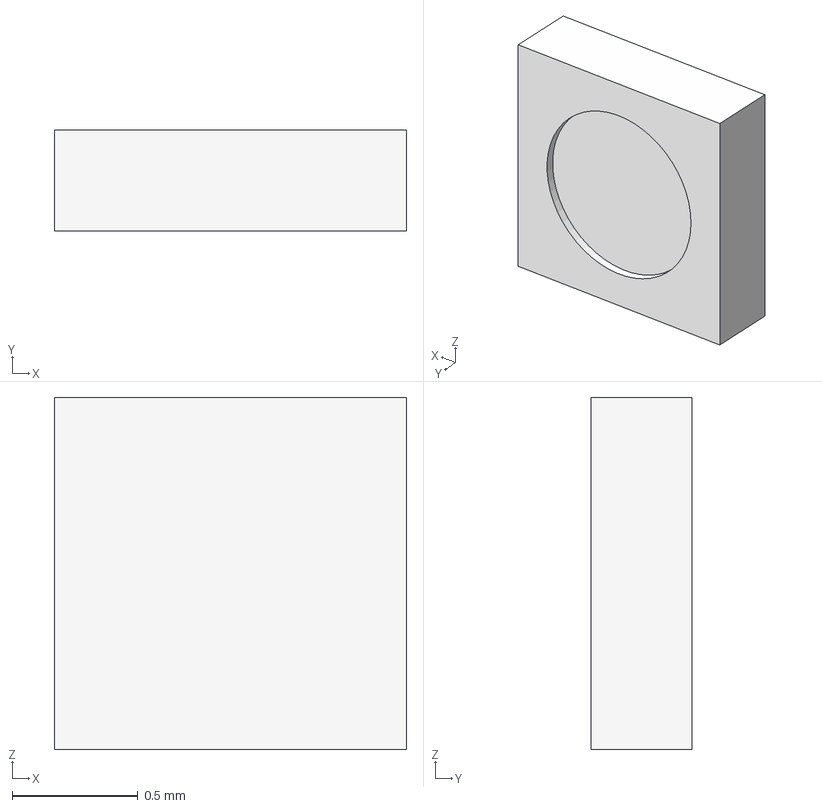
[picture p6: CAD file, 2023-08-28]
LED Model.stp
1.40 x 0.4 x 1.40 mm

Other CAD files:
LED Model.stl

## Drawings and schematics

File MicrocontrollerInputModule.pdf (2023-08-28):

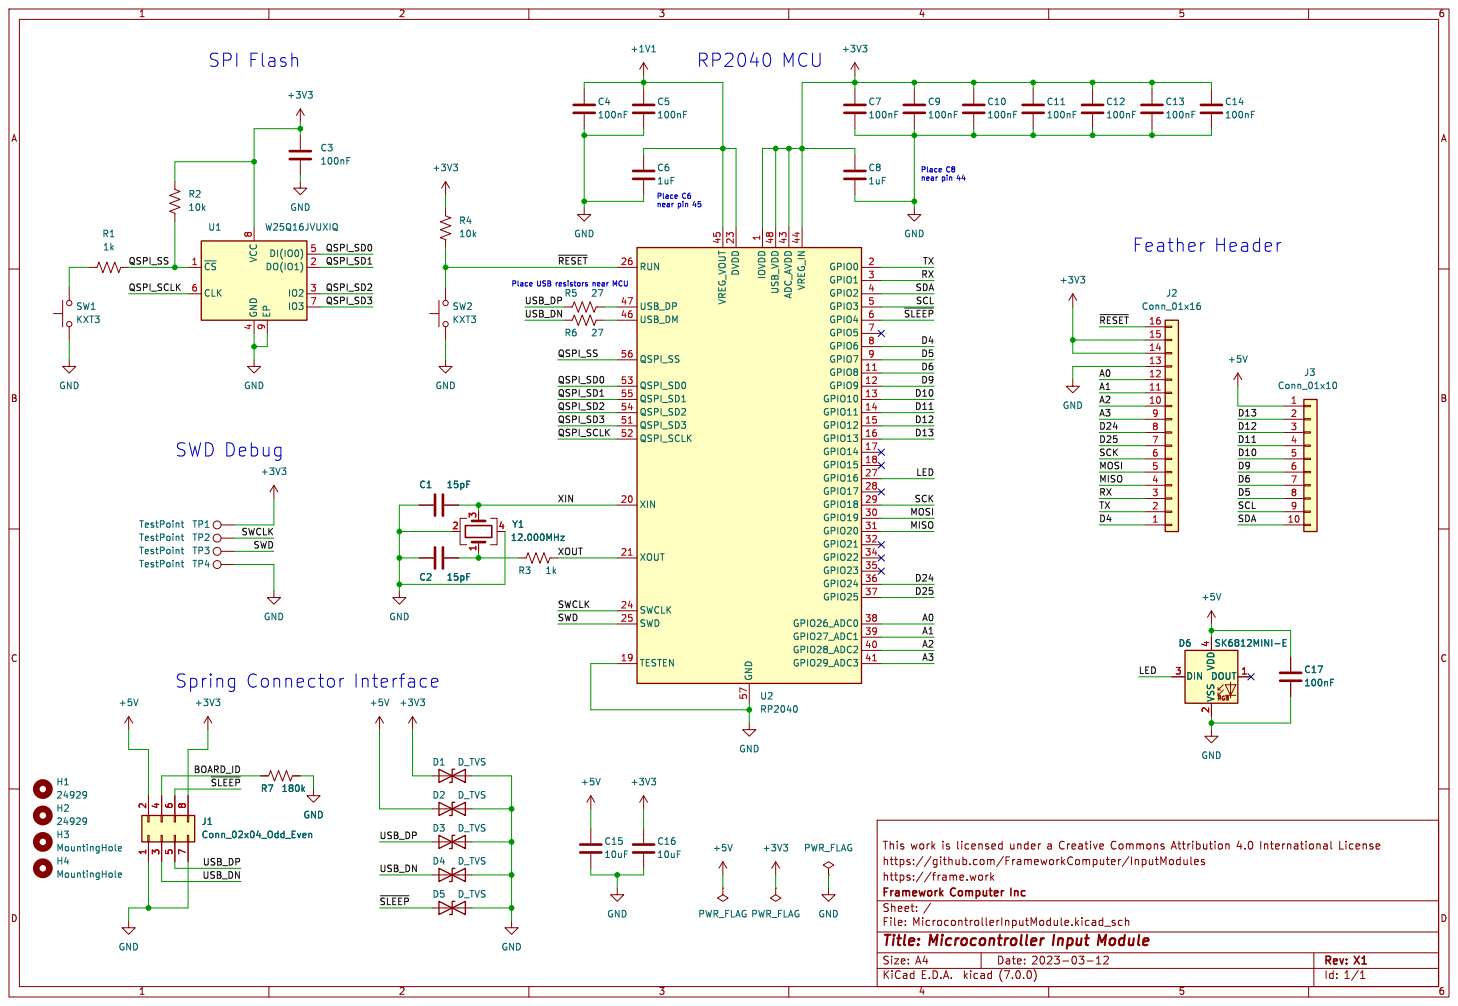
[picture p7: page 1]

1 GPIO8 11 GPIO9 12 GPIO10 13 GPIO11 14 GPIO12 15 GPIO13 16 GPIO14 17 GPIO15 18 TESTEN 19 GPIO0 2 XIN 20 XOUT 21 DVDD 23 SWCLK 24 SWD 25 RUN 26 GPIO16 27 GPIO17 28 GPIO18 29 GPIO1 3 GPIO19 30 GPIO20 31 GPIO21 32 GPIO22 34 GPIO23 35 GPIO24 36 GPIO25 37 GPIO26_ADC0 38 GPIO27_ADC1 39 GPIO2 4 GPIO28_ADC2 40 GPIO29_ADC3 41 ADC_AVDD 43 VREG_IN 44 VREG_VOUT 45 USB_DM 46 USB_DP 47 USB_VDD 48 GPIO3 5 QSPI_SD3 51 QSPI_SCLK 52 QSPI_SD0 53 QSPI_SD2 54 QSPI_SD1 55 QSPI_SS 56 GND 57 GPIO4 6 GPIO5 7 GPIO6 8 GPIO7 9 U2 RP2040 +5V +3V3 GND PWR_FLAG PWR_FLAG

Id: 1/1 Title: Microcontroller Input Module

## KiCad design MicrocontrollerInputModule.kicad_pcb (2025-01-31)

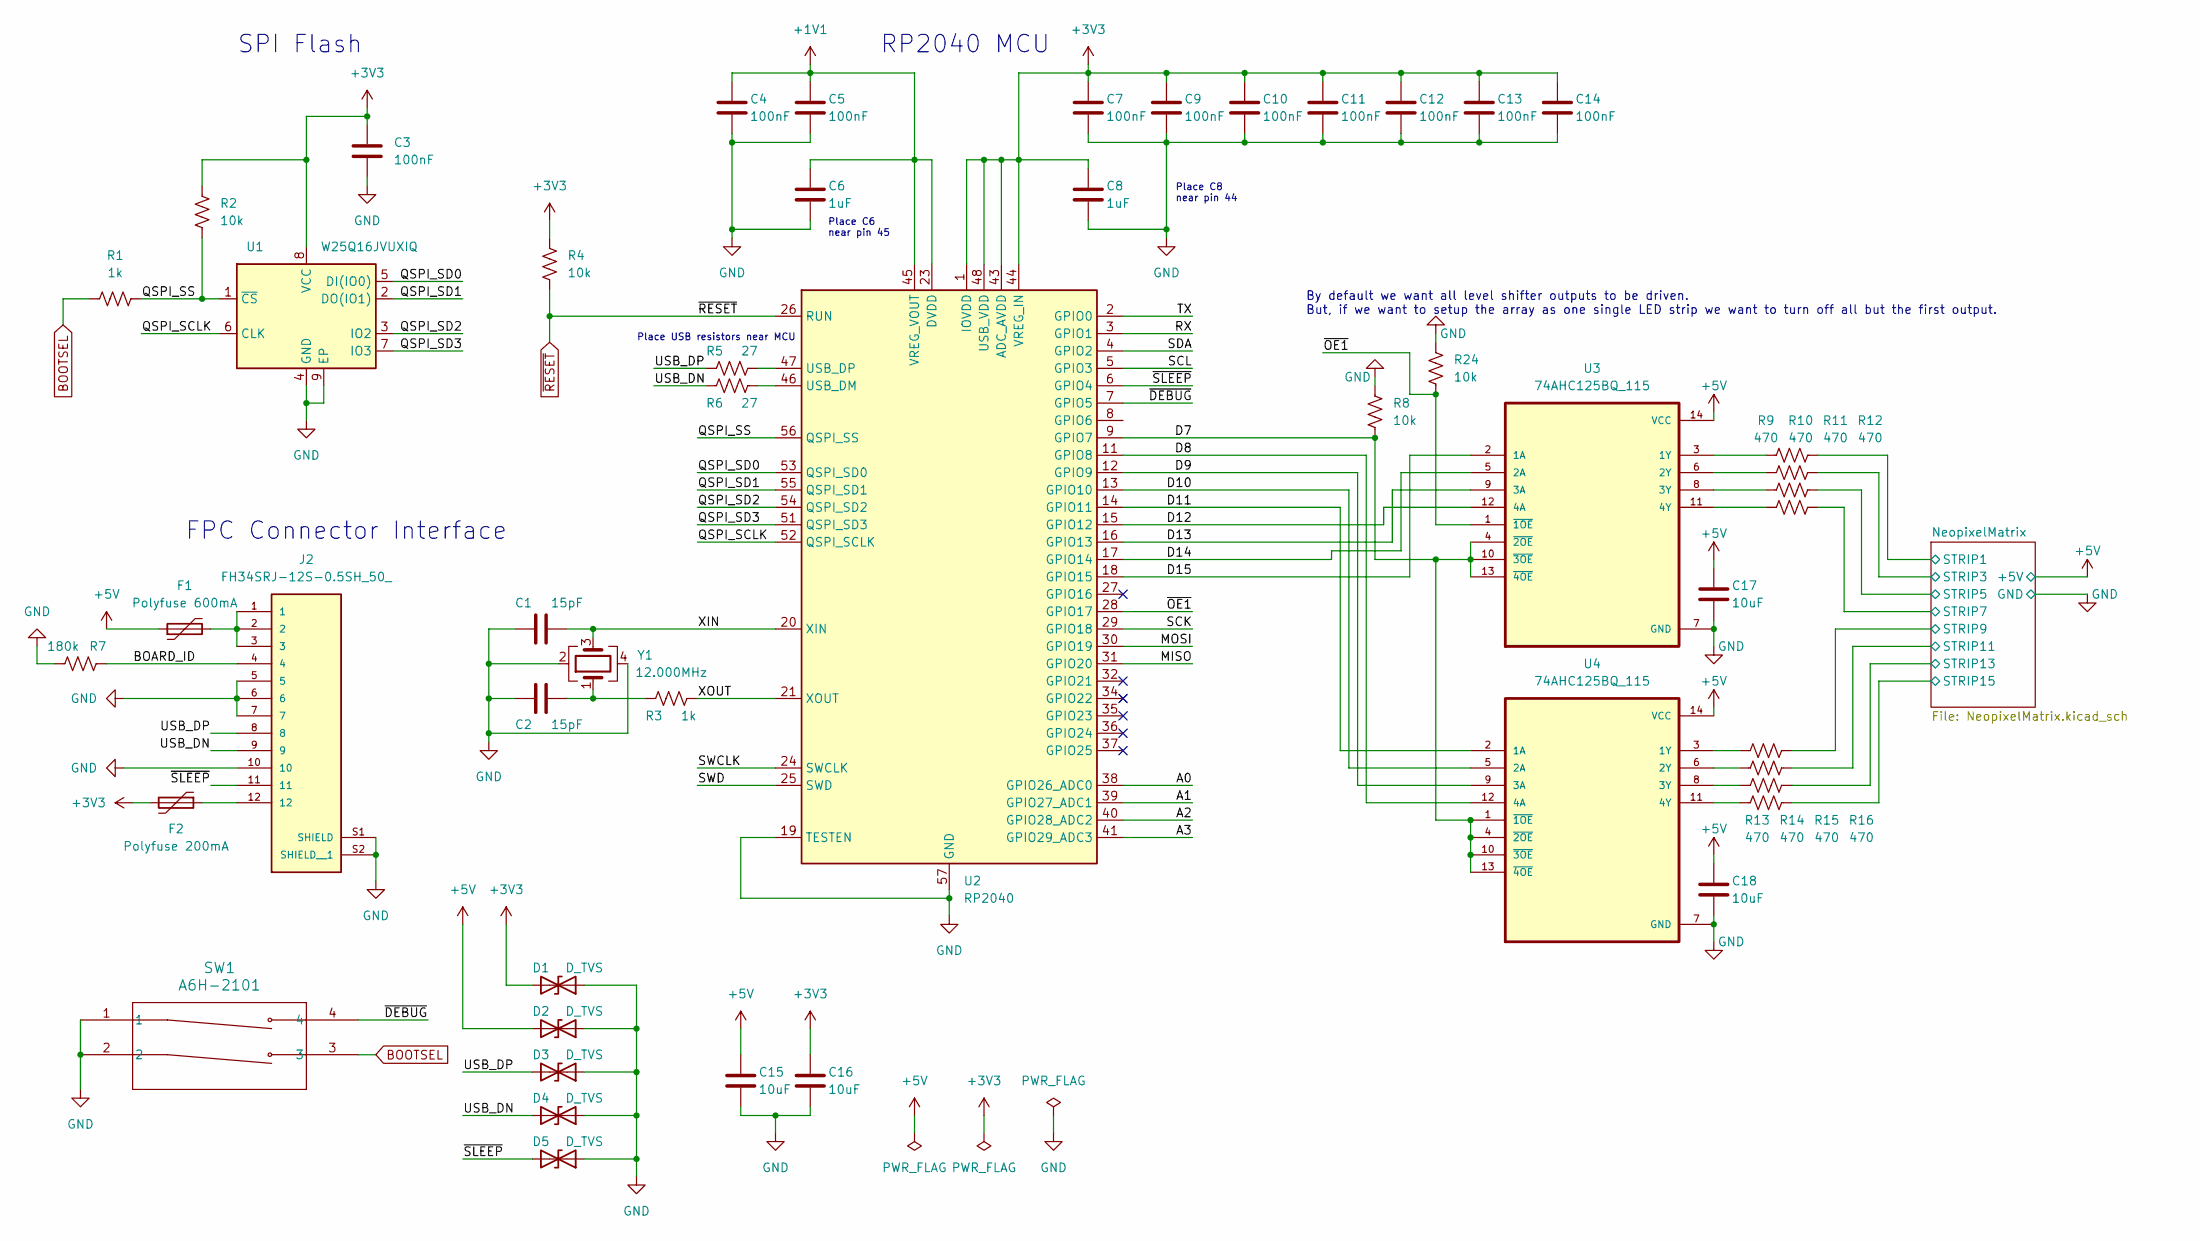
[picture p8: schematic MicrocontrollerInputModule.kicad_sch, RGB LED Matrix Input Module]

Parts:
C1, C2: 15pF; C_0402_1005Metric; LCSC Part # C76950
C3, C4, C5, C7, C9, C10, C11, C12, C13, C14: 100nF; C_0402_1005Metric; LCSC Part # C1525
C6, C8: 1uF; C_0402_1005Metric; LCSC Part # C29266
C15, C16, C17, C18: 10uF; C_0603_1608Metric; LCSC Part # C19702
D1, D2, D3, D4, D5: D_TVS; D_0402_1005Metric; LCSC Part # C468904
F1: Polyfuse 600mA; R_1206_3216Metric; LCSC Part # C883122
F2: Polyfuse 200mA; R_1206_3216Metric; LCSC Part # C910826
J2: FH34SRJ-12S-0.5SH_50_; HRS_FH34SRJ-12S-0.5SH_50_; LCSC Part # C424659
R1, R3: 1k; R_0402_1005Metric; LCSC Part # C106235
R2, R4, R8, R24: 10k; R_0402_1005Metric; LCSC Part # C60490
R5, R6: 27; R_0402_1005Metric; LCSC Part # C138021
R7: 180k; R_0402_1005Metric; LCSC Part # C138046
R9, R10, R11, R12, R13, R14, R15, R16: 470; R_0402_1005Metric; LCSC Part # C25117
SW1: A6H-2101; SW_A6H-2101_OMR; LCSC Part # C224990
U1: W25Q16JVUXIQ; SON-8-1EP_3x2mm_P0.5mm_EP0.2x1.6mm; LCSC Part # C2843335
U2: RP2040; QFN-56-1EP_7x7mm_P0.4mm_EP3.2x3.2mm; LCSC Part # C2040
U3, U4: 74AHC125BQ_115; QFN50P300X250X100-15N; LCSC Part # C554218
Y1: 12.000MHz; Crystal_SMD_3225-4Pin_3.2x2.5mm; LCSC Part # C7294551

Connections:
+1V1: C4.1, C5.1, C6.1, U2.23 (DVDD), U2.45 (VREG_VOUT), U2.50 (DVDD)
+3V3: C3.1, C7.1, C8.1, C9.1, C10.1, C11.1, C12.1, C13.1, C14.1, C16.1, D1.2 (A2), F2.2, R2.1, R4.1, U1.8 (VCC), U2.1 (IOVDD), U2.10 (IOVDD), U2.22 (IOVDD), U2.33 (IOVDD), U2.42 (IOVDD), U2.43 (ADC_AVDD), U2.44 (VREG_IN), U2.48 (USB_VDD), U2.49 (IOVDD)
+5V: C15.1, C17.1, C18.1, D2.2 (A2), F1.1, U3.14 (VCC), U4.14 (VCC); also elsewhere on the board
/A0: U2.38 (GPIO26_ADC0)
/A1: U2.39 (GPIO27_ADC1)
/A2: U2.40 (GPIO28_ADC2)
/A3: U2.41 (GPIO29_ADC3)
/BOARD_ID: J2.4, R7.1
/D7: R8.2, U2.9 (GPIO7), U3.4 (~2OE), U3.10 (~3OE), U3.13 (~4OE), U4.1 (~1OE), U4.4 (~2OE), U4.10 (~3OE), U4.13 (~4OE)
/D8: U2.11 (GPIO8), U4.12 (4A)
/D9: U2.12 (GPIO9), U4.9 (3A)
/D10: U2.13 (GPIO10), U4.5 (2A)
/D11: U2.14 (GPIO11), U4.2 (1A)
/D12: U2.15 (GPIO12), U3.12 (4A)
/D13: U2.16 (GPIO13), U3.9 (3A)
/D14: U2.17 (GPIO14), U3.5 (2A)
/D15: U2.18 (GPIO15), U3.2 (1A)
/MISO: U2.31 (GPIO20)
/MOSI: U2.30 (GPIO19)
/NeopixelMatrix/STRIP1: R9.2; also elsewhere on the board
/NeopixelMatrix/STRIP3: R10.2; also elsewhere on the board
/NeopixelMatrix/STRIP5: R11.2; also elsewhere on the board
/NeopixelMatrix/STRIP7: R12.2; also elsewhere on the board
/NeopixelMatrix/STRIP9: R13.2; also elsewhere on the board
/NeopixelMatrix/STRIP11: R14.2; also elsewhere on the board
/NeopixelMatrix/STRIP13: R15.2; also elsewhere on the board
/NeopixelMatrix/STRIP15: R16.2; also elsewhere on the board
/QSPI_SCLK: U1.6 (CLK), U2.52 (QSPI_SCLK)
/QSPI_SD0: U1.5 (DI(IO0)), U2.53 (QSPI_SD0)
/QSPI_SD1: U1.2 (DO(IO1)), U2.55 (QSPI_SD1)
/QSPI_SD2: U1.3 (IO2), U2.54 (QSPI_SD2)
/QSPI_SD3: U1.7 (IO3), U2.51 (QSPI_SD3)
/QSPI_SS: R1.2, R2.2, U1.1 (~CS), U2.56 (QSPI_SS)
/RX: U2.3 (GPIO1)
/SCK: U2.29 (GPIO18)
/SCL: U2.5 (GPIO3)
/SDA: U2.4 (GPIO2)
/SWCLK: U2.24 (SWCLK)
/SWD: U2.25 (SWD)
/TX: U2.2 (GPIO0)
/USB_DN: D4.2 (A2), J2.9, R6.1
/USB_DP: D3.2 (A2), J2.8, R5.1
/XIN: C1.2, U2.20 (XIN), Y1.3
/XOUT: R3.2, U2.21 (XOUT)
/~DEBUG: SW1.4, U2.7 (GPIO5)
/~OE1: R24.2, U2.28 (GPIO17), U3.1 (~1OE)
/~SLEEP: D5.2 (A2), J2.11, U2.6 (GPIO4)
BOOTSEL: R1.1, SW1.3
GND: C1.1, C2.1, C3.2, C4.2, C5.2, C6.2, C7.2, C8.2, C9.2, C10.2, C11.2, C12.2, C13.2, C14.2, C15.2, C16.2, C17.2, C18.2, D1.1 (A1), D2.1 (A1), D3.1 (A1), D4.1 (A1), D5.1 (A1), J2.5, J2.6, J2.7, J2.10, J2.S1 (SHIELD), J2.S2 (SHIELD__1), R7.2, R8.1, R24.1, SW1.1, SW1.2, U1.4 (GND), U1.9 (EP), U2.19 (TESTEN), U2.57 (GND), U3.7 (GND), U4.7 (GND), Y1.2, Y1.4; also elsewhere on the board
unnamed: C2.2, R3.1, Y1.1
unnamed: F1.2, J2.1, J2.2, J2.3
unnamed: F2.1, J2.12
unnamed: R6.2, U2.46 (USB_DM)
unnamed: R5.2, U2.47 (USB_DP)
unnamed: R9.1, U3.3 (1Y)
unnamed: R10.1, U3.6 (2Y)
unnamed: R11.1, U3.8 (3Y)
unnamed: R12.1, U3.11 (4Y)
unnamed: R13.1, U4.3 (1Y)
unnamed: R14.1, U4.6 (2Y)
unnamed: R15.1, U4.8 (3Y)
unnamed: R16.1, U4.11 (4Y)
~RESET: R4.2, U2.26 (RUN)

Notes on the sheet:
By default we want all level shifter outputs to be driven. But, if we want to setup the array as one single LED strip we want to turn off all but the first output.
SPI Flash
Place C8 near pin 44
Place USB resistors near MCU
Place C6 near pin 45
FPC Connector Interface
RP2040 MCU

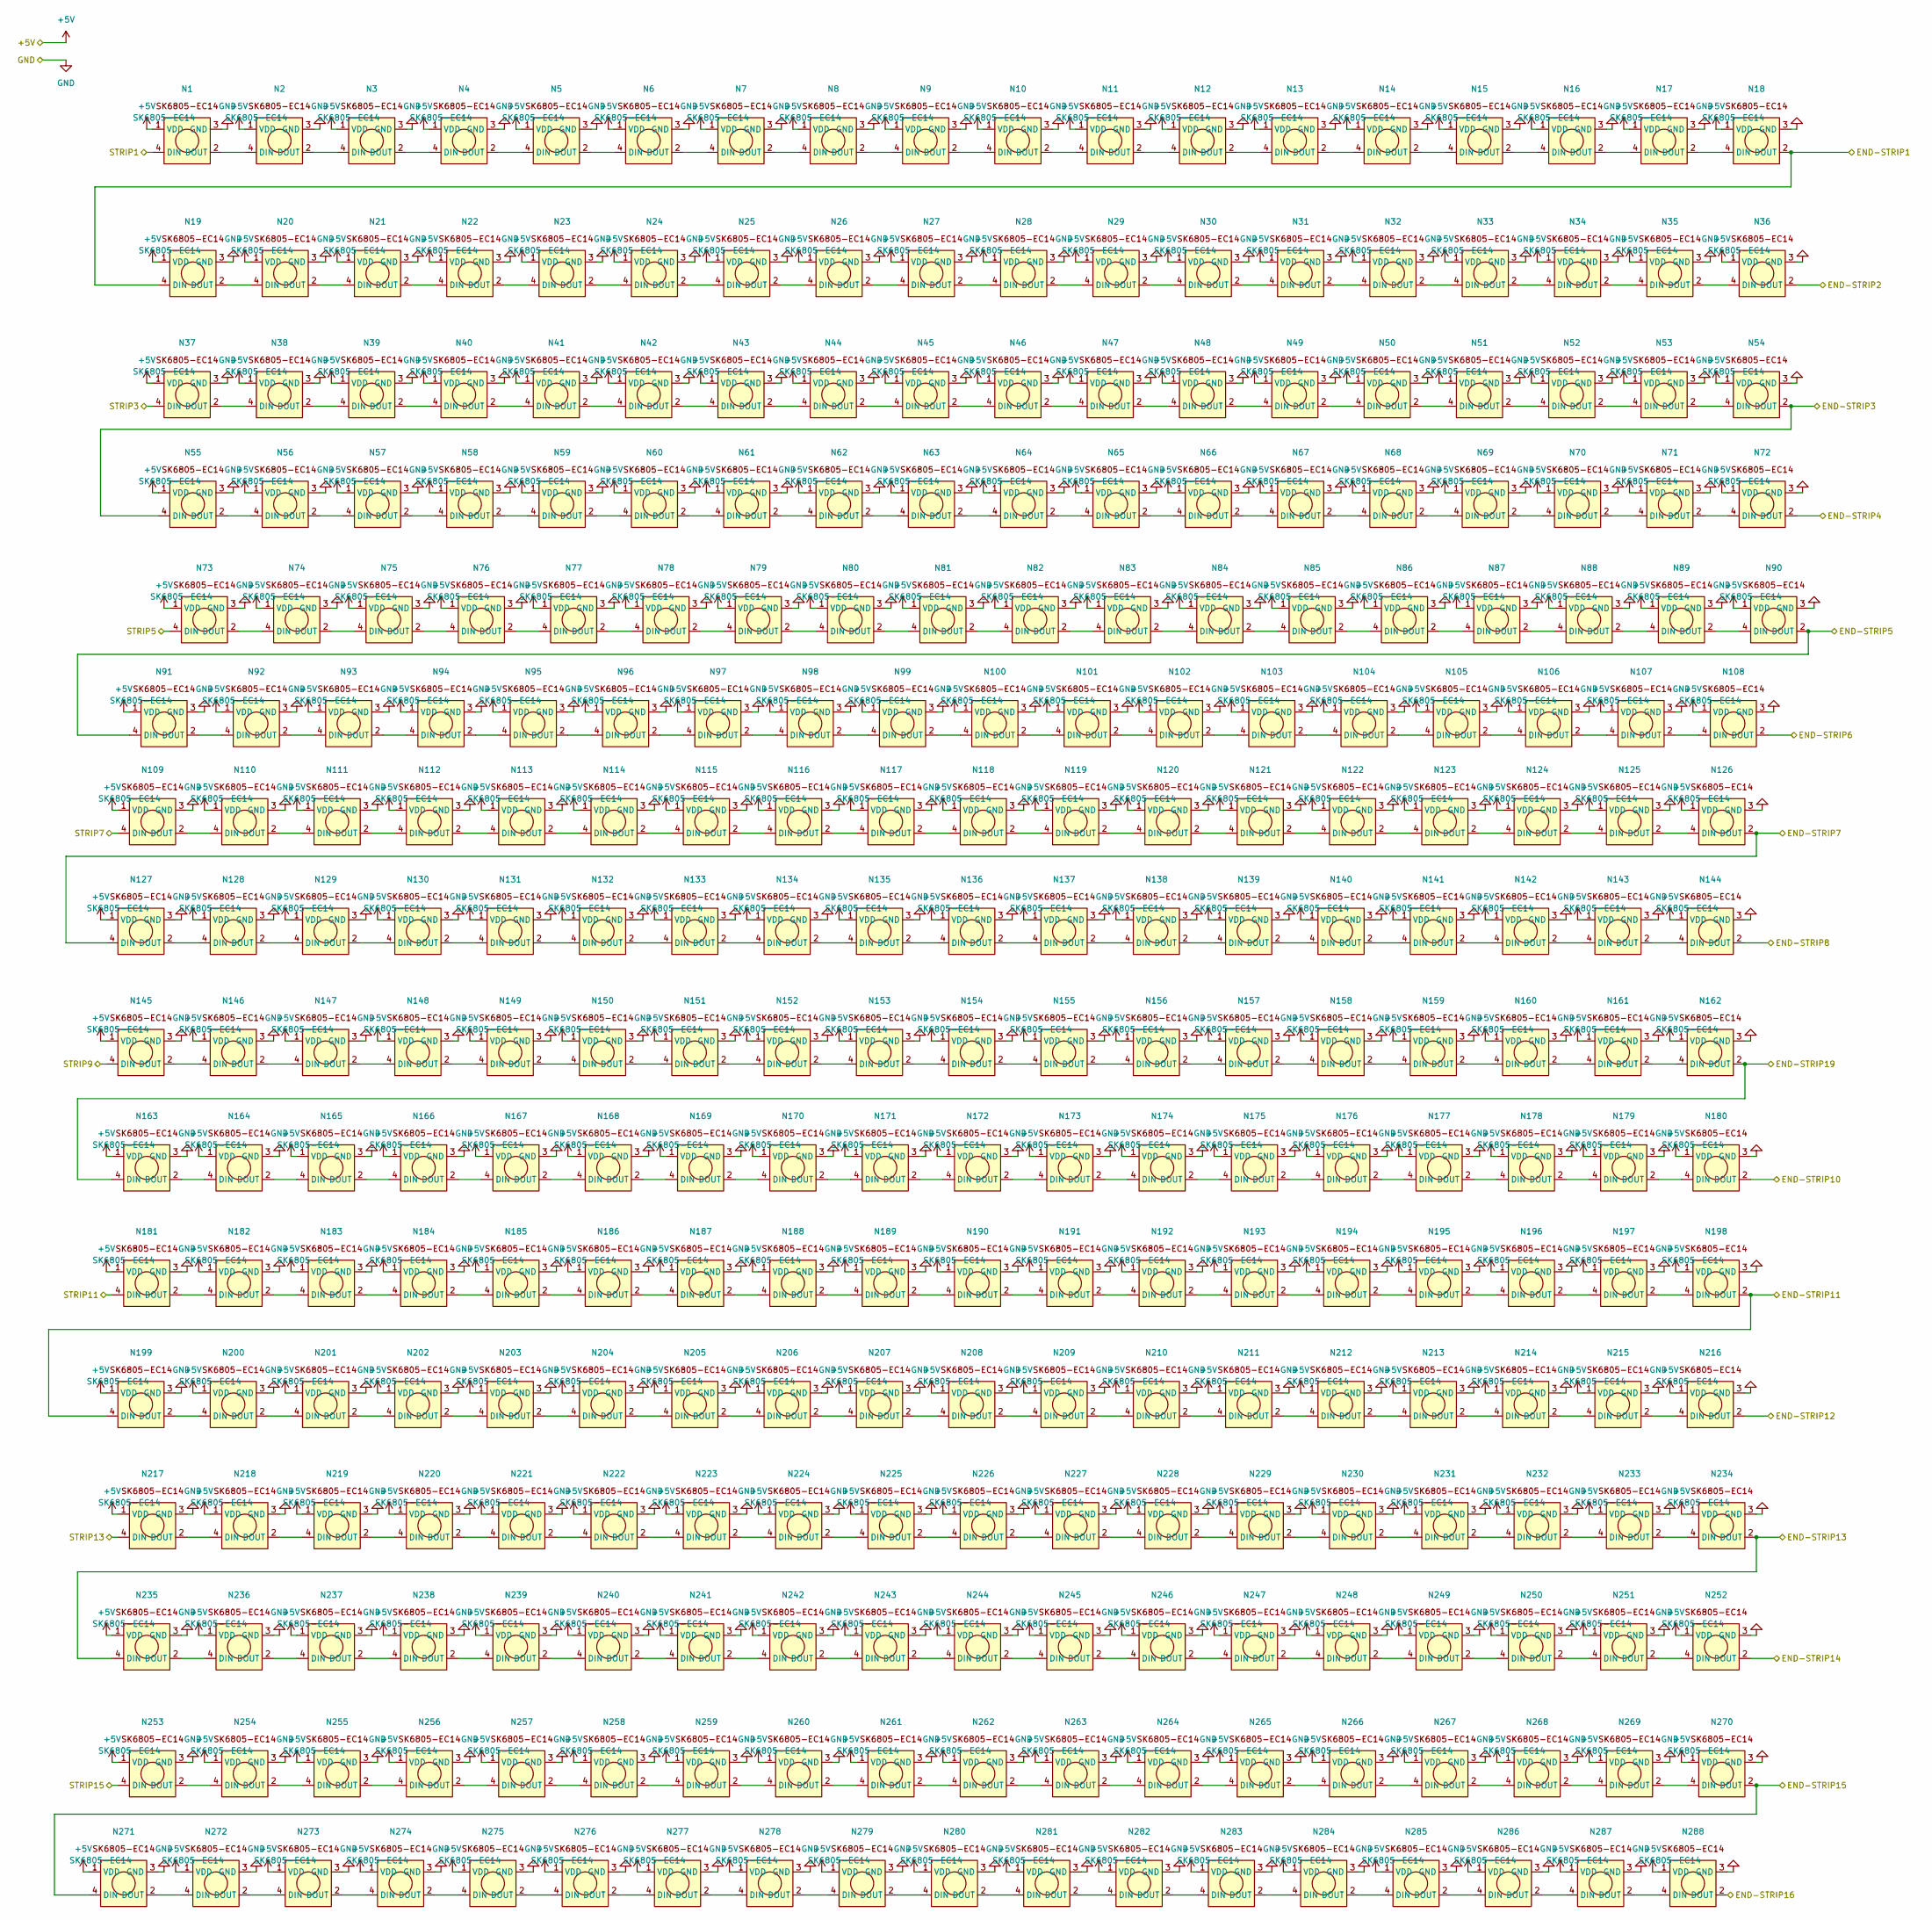
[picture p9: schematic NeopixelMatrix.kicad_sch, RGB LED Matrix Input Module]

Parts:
N1, N2, N3, N4, N5, N6, N7, N8, N9, N10, N11, N12, N13, N14, N15, N16, N17, N18, N19, N20, N21, N22, N23, N24, N25, N26, N27, N28, N29, N30, N31, N32, N33, N34, N35, N36, N37, N38, N39, N40, N41, N42, N43, N44, N45, N46, N47, N48, N49, N50, N51, N52, N53, N54, N55, N56, N57, N58, N59, N60, N61, N62, N63, N64, N65, N66, N67, N68, N69, N70, N71, N72, N73, N74, N75, N76, N77, N78, N79, N80, N81, N82, N83, N84, N85, N86, N87, N88, N89, N90, N91, N92, N93, N94, N95, N96, N97, N98, N99, N100, N101, N102, N103, N104, N105, N106, N107, N108, N109, N110, N111, N112, N113, N114, N115, N116, N117, N118, N119, N120, N121, N122, N123, N124, N125, N126, N127, N128, N129, N130, N131, N132, N133, N134, N135, N136, N137, N138, N139, N140, N141, N142, N143, N144, N145, N146, N147, N148, N149, N150, N151, N152, N153, N154, N155, N156, N157, N158, N159, N160, N161, N162, N163, N164, N165, N166, N167, N168, N169, N170, N171, N172, N173, N174, N175, N176, N177, N178, N179, N180, N181, N182, N183, N184, N185, N186, N187, N188, N189, N190, N191, N192, N193, N194, N195, N196, N197, N198, N199, N200, N201, N202, N203, N204, N205, N206, N207, N208, N209, N210, N211, N212, N213, N214, N215, N216, N217, N218, N219, N220, N221, N222, N223, N224, N225, N226, N227, N228, N229, N230, N231, N232, N233, N234, N235, N236, N237, N238, N239, N240, N241, N242, N243, N244, N245, N246, N247, N248, N249, N250, N251, N252, N253, N254, N255, N256, N257, N258, N259, N260, N261, N262, N263, N264, N265, N266, N267, N268, N269, N270, N271, N272, N273, N274, N275, N276, N277, N278, N279, N280, N281, N282, N283, N284, N285, N286, N287, N288: SK6805-EC14; LCSC Part # C2909055

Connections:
+5V: N1.1 (VDD), N2.1 (VDD), N3.1 (VDD), N4.1 (VDD), N5.1 (VDD), N6.1 (VDD), N7.1 (VDD), N8.1 (VDD), N9.1 (VDD), N10.1 (VDD), N11.1 (VDD), N12.1 (VDD), N13.1 (VDD), N14.1 (VDD), N15.1 (VDD), N16.1 (VDD), N17.1 (VDD), N18.1 (VDD), N19.1 (VDD), N20.1 (VDD), N21.1 (VDD), N22.1 (VDD), N23.1 (VDD), N24.1 (VDD), N25.1 (VDD), N26.1 (VDD), N27.1 (VDD), N28.1 (VDD), N29.1 (VDD), N30.1 (VDD), N31.1 (VDD), N32.1 (VDD), N33.1 (VDD), N34.1 (VDD), N35.1 (VDD), N36.1 (VDD), N37.1 (VDD), N38.1 (VDD), N39.1 (VDD), N40.1 (VDD), N41.1 (VDD), N42.1 (VDD), N43.1 (VDD), N44.1 (VDD), N45.1 (VDD), N46.1 (VDD), N47.1 (VDD), N48.1 (VDD), N49.1 (VDD), N50.1 (VDD), N51.1 (VDD), N52.1 (VDD), N53.1 (VDD), N54.1 (VDD), N55.1 (VDD), N56.1 (VDD), N57.1 (VDD), N58.1 (VDD), N59.1 (VDD), N60.1 (VDD), N61.1 (VDD), N62.1 (VDD), N63.1 (VDD), N64.1 (VDD), N65.1 (VDD), N66.1 (VDD), N67.1 (VDD), N68.1 (VDD), N69.1 (VDD), N70.1 (VDD), N71.1 (VDD), N72.1 (VDD), N73.1 (VDD), N74.1 (VDD), N75.1 (VDD), N76.1 (VDD), N77.1 (VDD), N78.1 (VDD), N79.1 (VDD), N80.1 (VDD), N81.1 (VDD), N82.1 (VDD), N83.1 (VDD), N84.1 (VDD), N85.1 (VDD), N86.1 (VDD), N87.1 (VDD), N88.1 (VDD), N89.1 (VDD), N90.1 (VDD), N91.1 (VDD), N92.1 (VDD), N93.1 (VDD), N94.1 (VDD), N95.1 (VDD), N96.1 (VDD), N97.1 (VDD), N98.1 (VDD), N99.1 (VDD), N100.1 (VDD), N101.1 (VDD), N102.1 (VDD), N103.1 (VDD), N104.1 (VDD), N105.1 (VDD), N106.1 (VDD), N107.1 (VDD), N108.1 (VDD), N109.1 (VDD), N110.1 (VDD), N111.1 (VDD), N112.1 (VDD), N113.1 (VDD), N114.1 (VDD), N115.1 (VDD), N116.1 (VDD), N117.1 (VDD), N118.1 (VDD), N119.1 (VDD), N120.1 (VDD), N121.1 (VDD), N122.1 (VDD), N123.1 (VDD), N124.1 (VDD), N125.1 (VDD), N126.1 (VDD), N127.1 (VDD), N128.1 (VDD), N129.1 (VDD), N130.1 (VDD), N131.1 (VDD), N132.1 (VDD), N133.1 (VDD), N134.1 (VDD), N135.1 (VDD), N136.1 (VDD), N137.1 (VDD), N138.1 (VDD), N139.1 (VDD), N140.1 (VDD), N141.1 (VDD), N142.1 (VDD), N143.1 (VDD), N144.1 (VDD), N145.1 (VDD), N146.1 (VDD), N147.1 (VDD), N148.1 (VDD), N149.1 (VDD), N150.1 (VDD), N151.1 (VDD), N152.1 (VDD), N153.1 (VDD), N154.1 (VDD), N155.1 (VDD), N156.1 (VDD), N157.1 (VDD), N158.1 (VDD), N159.1 (VDD), N160.1 (VDD), N161.1 (VDD), N162.1 (VDD), N163.1 (VDD), N164.1 (VDD), N165.1 (VDD), N166.1 (VDD), N167.1 (VDD), N168.1 (VDD), N169.1 (VDD), N170.1 (VDD), N171.1 (VDD), N172.1 (VDD), N173.1 (VDD), N174.1 (VDD), N175.1 (VDD), N176.1 (VDD), N177.1 (VDD), N178.1 (VDD), N179.1 (VDD), N180.1 (VDD), N181.1 (VDD), N182.1 (VDD), N183.1 (VDD), N184.1 (VDD), N185.1 (VDD), N186.1 (VDD), N187.1 (VDD), N188.1 (VDD), N189.1 (VDD), N190.1 (VDD), N191.1 (VDD), N192.1 (VDD), N193.1 (VDD), N194.1 (VDD), N195.1 (VDD), N196.1 (VDD), N197.1 (VDD), N198.1 (VDD), N199.1 (VDD), N200.1 (VDD), N201.1 (VDD), N202.1 (VDD), N203.1 (VDD), N204.1 (VDD), N205.1 (VDD), N206.1 (VDD), N207.1 (VDD), N208.1 (VDD), N209.1 (VDD), N210.1 (VDD), N211.1 (VDD), N212.1 (VDD), N213.1 (VDD), N214.1 (VDD), N215.1 (VDD), N216.1 (VDD), N217.1 (VDD), N218.1 (VDD), N219.1 (VDD), N220.1 (VDD), N221.1 (VDD), N222.1 (VDD), N223.1 (VDD), N224.1 (VDD), N225.1 (VDD), N226.1 (VDD), N227.1 (VDD), N228.1 (VDD), N229.1 (VDD), N230.1 (VDD), N231.1 (VDD), N232.1 (VDD), N233.1 (VDD), N234.1 (VDD), N235.1 (VDD), N236.1 (VDD), N237.1 (VDD), N238.1 (VDD), N239.1 (VDD), N240.1 (VDD), N241.1 (VDD), N242.1 (VDD), N243.1 (VDD), N244.1 (VDD), N245.1 (VDD), N246.1 (VDD), N247.1 (VDD), N248.1 (VDD), N249.1 (VDD), N250.1 (VDD), N251.1 (VDD), N252.1 (VDD), N253.1 (VDD), N254.1 (VDD), N255.1 (VDD), N256.1 (VDD), N257.1 (VDD), N258.1 (VDD), N259.1 (VDD), N260.1 (VDD), N261.1 (VDD), N262.1 (VDD), N263.1 (VDD), N264.1 (VDD), N265.1 (VDD), N266.1 (VDD), N267.1 (VDD), N268.1 (VDD), N269.1 (VDD), N270.1 (VDD), N271.1 (VDD), N272.1 (VDD), N273.1 (VDD), N274.1 (VDD), N275.1 (VDD), N276.1 (VDD), N277.1 (VDD), N278.1 (VDD), N279.1 (VDD), N280.1 (VDD), N281.1 (VDD), N282.1 (VDD), N283.1 (VDD), N284.1 (VDD), N285.1 (VDD), N286.1 (VDD), N287.1 (VDD), N288.1 (VDD); also elsewhere on the board
/NeopixelMatrix/END-STRIP1: N18.2 (DOUT), N19.4 (DIN)
/NeopixelMatrix/END-STRIP2: N36.2 (DOUT)
/NeopixelMatrix/END-STRIP3: N54.2 (DOUT), N55.4 (DIN)
/NeopixelMatrix/END-STRIP4: N72.2 (DOUT)
/NeopixelMatrix/END-STRIP5: N90.2 (DOUT), N91.4 (DIN)
/NeopixelMatrix/END-STRIP6: N108.2 (DOUT)
/NeopixelMatrix/END-STRIP7: N126.2 (DOUT), N127.4 (DIN)
/NeopixelMatrix/END-STRIP8: N144.2 (DOUT)
/NeopixelMatrix/END-STRIP10: N180.2 (DOUT)
/NeopixelMatrix/END-STRIP11: N198.2 (DOUT), N199.4 (DIN)
/NeopixelMatrix/END-STRIP12: N216.2 (DOUT)
/NeopixelMatrix/END-STRIP13: N234.2 (DOUT), N235.4 (DIN)
/NeopixelMatrix/END-STRIP14: N252.2 (DOUT)
/NeopixelMatrix/END-STRIP15: N270.2 (DOUT), N271.4 (DIN)
/NeopixelMatrix/END-STRIP16: N288.2 (DOUT)
/NeopixelMatrix/END-STRIP19: N162.2 (DOUT), N163.4 (DIN)
/NeopixelMatrix/STRIP1: N1.4 (DIN); also elsewhere on the board
/NeopixelMatrix/STRIP3: N37.4 (DIN); also elsewhere on the board
/NeopixelMatrix/STRIP5: N73.4 (DIN); also elsewhere on the board
/NeopixelMatrix/STRIP7: N109.4 (DIN); also elsewhere on the board
/NeopixelMatrix/STRIP9: N145.4 (DIN); also elsewhere on the board
/NeopixelMatrix/STRIP11: N181.4 (DIN); also elsewhere on the board
/NeopixelMatrix/STRIP13: N217.4 (DIN); also elsewhere on the board
/NeopixelMatrix/STRIP15: N253.4 (DIN); also elsewhere on the board
GND: N1.3 (GND), N2.3 (GND), N3.3 (GND), N4.3 (GND), N5.3 (GND), N6.3 (GND), N7.3 (GND), N8.3 (GND), N9.3 (GND), N10.3 (GND), N11.3 (GND), N12.3 (GND), N13.3 (GND), N14.3 (GND), N15.3 (GND), N16.3 (GND), N17.3 (GND), N18.3 (GND), N19.3 (GND), N20.3 (GND), N21.3 (GND), N22.3 (GND), N23.3 (GND), N24.3 (GND), N25.3 (GND), N26.3 (GND), N27.3 (GND), N28.3 (GND), N29.3 (GND), N30.3 (GND), N31.3 (GND), N32.3 (GND), N33.3 (GND), N34.3 (GND), N35.3 (GND), N36.3 (GND), N37.3 (GND), N38.3 (GND), N39.3 (GND), N40.3 (GND), N41.3 (GND), N42.3 (GND), N43.3 (GND), N44.3 (GND), N45.3 (GND), N46.3 (GND), N47.3 (GND), N48.3 (GND), N49.3 (GND), N50.3 (GND), N51.3 (GND), N52.3 (GND), N53.3 (GND), N54.3 (GND), N55.3 (GND), N56.3 (GND), N57.3 (GND), N58.3 (GND), N59.3 (GND), N60.3 (GND), N61.3 (GND), N62.3 (GND), N63.3 (GND), N64.3 (GND), N65.3 (GND), N66.3 (GND), N67.3 (GND), N68.3 (GND), N69.3 (GND), N70.3 (GND), N71.3 (GND), N72.3 (GND), N73.3 (GND), N74.3 (GND), N75.3 (GND), N76.3 (GND), N77.3 (GND), N78.3 (GND), N79.3 (GND), N80.3 (GND), N81.3 (GND), N82.3 (GND), N83.3 (GND), N84.3 (GND), N85.3 (GND), N86.3 (GND), N87.3 (GND), N88.3 (GND), N89.3 (GND), N90.3 (GND), N91.3 (GND), N92.3 (GND), N93.3 (GND), N94.3 (GND), N95.3 (GND), N96.3 (GND), N97.3 (GND), N98.3 (GND), N99.3 (GND), N100.3 (GND), N101.3 (GND), N102.3 (GND), N103.3 (GND), N104.3 (GND), N105.3 (GND), N106.3 (GND), N107.3 (GND), N108.3 (GND), N109.3 (GND), N110.3 (GND), N111.3 (GND), N112.3 (GND), N113.3 (GND), N114.3 (GND), N115.3 (GND), N116.3 (GND), N117.3 (GND), N118.3 (GND), N119.3 (GND), N120.3 (GND), N121.3 (GND), N122.3 (GND), N123.3 (GND), N124.3 (GND), N125.3 (GND), N126.3 (GND), N127.3 (GND), N128.3 (GND), N129.3 (GND), N130.3 (GND), N131.3 (GND), N132.3 (GND), N133.3 (GND), N134.3 (GND), N135.3 (GND), N136.3 (GND), N137.3 (GND), N138.3 (GND), N139.3 (GND), N140.3 (GND), N141.3 (GND), N142.3 (GND), N143.3 (GND), N144.3 (GND), N145.3 (GND), N146.3 (GND), N147.3 (GND), N148.3 (GND), N149.3 (GND), N150.3 (GND), N151.3 (GND), N152.3 (GND), N153.3 (GND), N154.3 (GND), N155.3 (GND), N156.3 (GND), N157.3 (GND), N158.3 (GND), N159.3 (GND), N160.3 (GND), N161.3 (GND), N162.3 (GND), N163.3 (GND), N164.3 (GND), N165.3 (GND), N166.3 (GND), N167.3 (GND), N168.3 (GND), N169.3 (GND), N170.3 (GND), N171.3 (GND), N172.3 (GND), N173.3 (GND), N174.3 (GND), N175.3 (GND), N176.3 (GND), N177.3 (GND), N178.3 (GND), N179.3 (GND), N180.3 (GND), N181.3 (GND), N182.3 (GND), N183.3 (GND), N184.3 (GND), N185.3 (GND), N186.3 (GND), N187.3 (GND), N188.3 (GND), N189.3 (GND), N190.3 (GND), N191.3 (GND), N192.3 (GND), N193.3 (GND), N194.3 (GND), N195.3 (GND), N196.3 (GND), N197.3 (GND), N198.3 (GND), N199.3 (GND), N200.3 (GND), N201.3 (GND), N202.3 (GND), N203.3 (GND), N204.3 (GND), N205.3 (GND), N206.3 (GND), N207.3 (GND), N208.3 (GND), N209.3 (GND), N210.3 (GND), N211.3 (GND), N212.3 (GND), N213.3 (GND), N214.3 (GND), N215.3 (GND), N216.3 (GND), N217.3 (GND), N218.3 (GND), N219.3 (GND), N220.3 (GND), N221.3 (GND), N222.3 (GND), N223.3 (GND), N224.3 (GND), N225.3 (GND), N226.3 (GND), N227.3 (GND), N228.3 (GND), N229.3 (GND), N230.3 (GND), N231.3 (GND), N232.3 (GND), N233.3 (GND), N234.3 (GND), N235.3 (GND), N236.3 (GND), N237.3 (GND), N238.3 (GND), N239.3 (GND), N240.3 (GND), N241.3 (GND), N242.3 (GND), N243.3 (GND), N244.3 (GND), N245.3 (GND), N246.3 (GND), N247.3 (GND), N248.3 (GND), N249.3 (GND), N250.3 (GND), N251.3 (GND), N252.3 (GND), N253.3 (GND), N254.3 (GND), N255.3 (GND), N256.3 (GND), N257.3 (GND), N258.3 (GND), N259.3 (GND), N260.3 (GND), N261.3 (GND), N262.3 (GND), N263.3 (GND), N264.3 (GND), N265.3 (GND), N266.3 (GND), N267.3 (GND), N268.3 (GND), N269.3 (GND), N270.3 (GND), N271.3 (GND), N272.3 (GND), N273.3 (GND), N274.3 (GND), N275.3 (GND), N276.3 (GND), N277.3 (GND), N278.3 (GND), N279.3 (GND), N280.3 (GND), N281.3 (GND), N282.3 (GND), N283.3 (GND), N284.3 (GND), N285.3 (GND), N286.3 (GND), N287.3 (GND), N288.3 (GND); also elsewhere on the board
unnamed: N1.2 (DOUT), N2.4 (DIN)
unnamed: N2.2 (DOUT), N3.4 (DIN)
unnamed: N3.2 (DOUT), N4.4 (DIN)
unnamed: N4.2 (DOUT), N5.4 (DIN)
unnamed: N5.2 (DOUT), N6.4 (DIN)
unnamed: N6.2 (DOUT), N7.4 (DIN)
unnamed: N7.2 (DOUT), N8.4 (DIN)
unnamed: N8.2 (DOUT), N9.4 (DIN)
unnamed: N9.2 (DOUT), N10.4 (DIN)
unnamed: N10.2 (DOUT), N11.4 (DIN)
unnamed: N11.2 (DOUT), N12.4 (DIN)
unnamed: N12.2 (DOUT), N13.4 (DIN)
unnamed: N13.2 (DOUT), N14.4 (DIN)
unnamed: N14.2 (DOUT), N15.4 (DIN)
unnamed: N15.2 (DOUT), N16.4 (DIN)
unnamed: N16.2 (DOUT), N17.4 (DIN)
unnamed: N17.2 (DOUT), N18.4 (DIN)
unnamed: N19.2 (DOUT), N20.4 (DIN)
unnamed: N20.2 (DOUT), N21.4 (DIN)
unnamed: N21.2 (DOUT), N22.4 (DIN)
unnamed: N22.2 (DOUT), N23.4 (DIN)
unnamed: N23.2 (DOUT), N24.4 (DIN)
unnamed: N24.2 (DOUT), N25.4 (DIN)
unnamed: N25.2 (DOUT), N26.4 (DIN)
unnamed: N26.2 (DOUT), N27.4 (DIN)
unnamed: N27.2 (DOUT), N28.4 (DIN)
unnamed: N28.2 (DOUT), N29.4 (DIN)
unnamed: N29.2 (DOUT), N30.4 (DIN)
unnamed: N30.2 (DOUT), N31.4 (DIN)
unnamed: N31.2 (DOUT), N32.4 (DIN)
unnamed: N32.2 (DOUT), N33.4 (DIN)
unnamed: N33.2 (DOUT), N34.4 (DIN)
unnamed: N34.2 (DOUT), N35.4 (DIN)
unnamed: N35.2 (DOUT), N36.4 (DIN)
unnamed: N37.2 (DOUT), N38.4 (DIN)
unnamed: N38.2 (DOUT), N39.4 (DIN)
unnamed: N39.2 (DOUT), N40.4 (DIN)
unnamed: N40.2 (DOUT), N41.4 (DIN)
unnamed: N41.2 (DOUT), N42.4 (DIN)
unnamed: N42.2 (DOUT), N43.4 (DIN)
unnamed: N43.2 (DOUT), N44.4 (DIN)
unnamed: N44.2 (DOUT), N45.4 (DIN)
unnamed: N45.2 (DOUT), N46.4 (DIN)
unnamed: N46.2 (DOUT), N47.4 (DIN)
unnamed: N47.2 (DOUT), N48.4 (DIN)
unnamed: N48.2 (DOUT), N49.4 (DIN)
unnamed: N49.2 (DOUT), N50.4 (DIN)
unnamed: N50.2 (DOUT), N51.4 (DIN)
unnamed: N51.2 (DOUT), N52.4 (DIN)
unnamed: N52.2 (DOUT), N53.4 (DIN)
unnamed: N53.2 (DOUT), N54.4 (DIN)
unnamed: N55.2 (DOUT), N56.4 (DIN)
unnamed: N56.2 (DOUT), N57.4 (DIN)
unnamed: N57.2 (DOUT), N58.4 (DIN)
unnamed: N58.2 (DOUT), N59.4 (DIN)
unnamed: N59.2 (DOUT), N60.4 (DIN)
unnamed: N60.2 (DOUT), N61.4 (DIN)
unnamed: N61.2 (DOUT), N62.4 (DIN)
unnamed: N62.2 (DOUT), N63.4 (DIN)
unnamed: N63.2 (DOUT), N64.4 (DIN)
unnamed: N64.2 (DOUT), N65.4 (DIN)
unnamed: N65.2 (DOUT), N66.4 (DIN)
unnamed: N66.2 (DOUT), N67.4 (DIN)
unnamed: N67.2 (DOUT), N68.4 (DIN)
unnamed: N68.2 (DOUT), N69.4 (DIN)
unnamed: N69.2 (DOUT), N70.4 (DIN)
unnamed: N70.2 (DOUT), N71.4 (DIN)
unnamed: N71.2 (DOUT), N72.4 (DIN)
unnamed: N73.2 (DOUT), N74.4 (DIN)
unnamed: N74.2 (DOUT), N75.4 (DIN)
unnamed: N75.2 (DOUT), N76.4 (DIN)
unnamed: N76.2 (DOUT), N77.4 (DIN)
unnamed: N77.2 (DOUT), N78.4 (DIN)
unnamed: N78.2 (DOUT), N79.4 (DIN)
unnamed: N79.2 (DOUT), N80.4 (DIN)
unnamed: N80.2 (DOUT), N81.4 (DIN)
unnamed: N81.2 (DOUT), N82.4 (DIN)
unnamed: N82.2 (DOUT), N83.4 (DIN)
unnamed: N83.2 (DOUT), N84.4 (DIN)
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

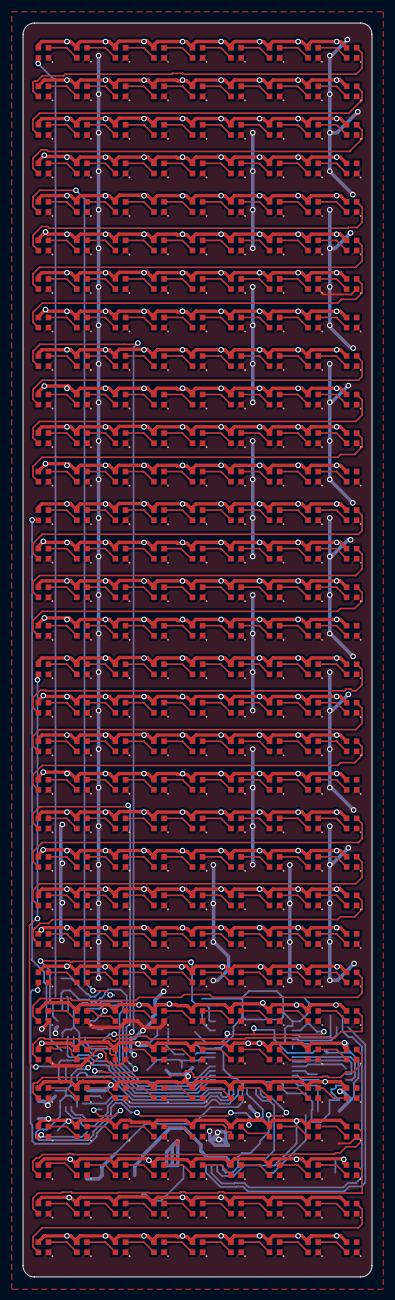
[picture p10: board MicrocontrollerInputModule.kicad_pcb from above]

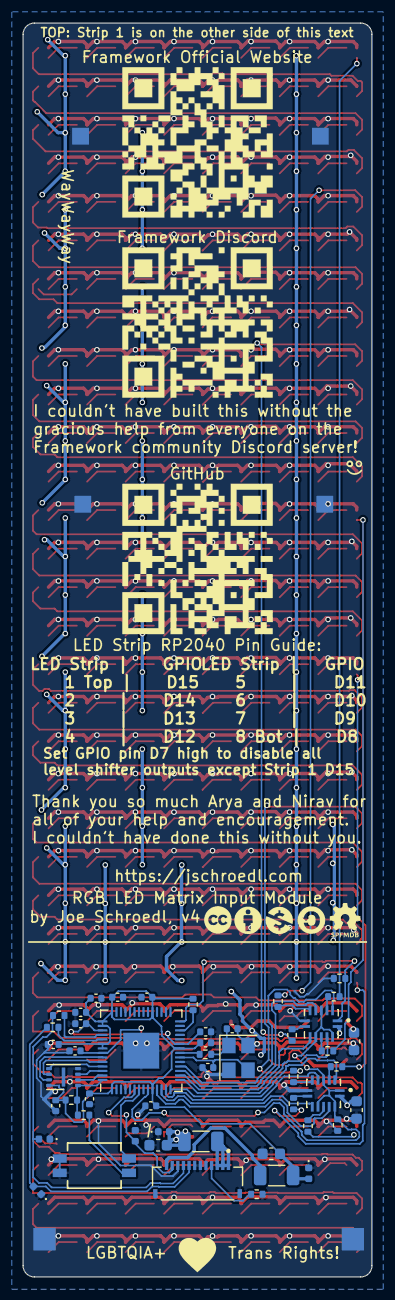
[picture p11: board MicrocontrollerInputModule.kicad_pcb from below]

Board: 2 copper layers, 31.0 x 111.4 mm, 337 parts (49 on the bottom side), 330 nets.

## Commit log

2023-10-14 Version 2
    [74AHC125BQ_115.step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]
2023-10-15 All traces ran. Zero DRC errors.
    Most of the DRC warnings can be ignored since they involve the LEDs and their footprints not including a certain layer or label.
    [MicrocontrollerInputModule.kicad_pcb]
2023-10-15 Fixed some routing issues for better Ground connections
    [MicrocontrollerInputModule.kicad_pcb]
2023-10-15 Added silkscreen
    [MicrocontrollerInputModule.kicad_pcb]
2023-10-15 PCB Assembly and Production Files
    [MicrocontrollerInputModule-B_Cu.gbr, MicrocontrollerInputModule-B_Mask.gbr, MicrocontrollerInputModule-B_Paste.gbr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]
2023-10-21 Added dip switch
    [MicrocontrollerInputModule.kicad_pcb, MicrocontrollerInputModule.kicad_sch]
2023-10-22 Arya Edits and Feedback plus DIP Switch
    [MicrocontrollerInputModule.kicad_pcb, MicrocontrollerInputModule.kicad_sch]
2023-10-22 Adjusting silk screen and some wires
    [MicrocontrollerInputModule.kicad_pcb, MicrocontrollerInputModule.kicad_sch]
2023-10-22 Fabrication edits
    [MicrocontrollerInputModule-B_Cu.gbl, MicrocontrollerInputModule-B_Mask.gbs, MicrocontrollerInputModule-B_Paste.gbp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]
2023-10-22 Added panelized kicad project folder
    [RGB-Panel-B_Cu.gbl, RGB-Panel-B_Mask.gbs, RGB-Panel-B_Paste.gbp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]
2023-10-22 Removed old gerber files
    [MicrocontrollerInputModule-B_Cu.gbl, MicrocontrollerInputModule-B_Cu.gbr, MicrocontrollerInputModule-B_Mask.gbr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]
2024-04-01 V3 update in preparation for sale
    [BOM-MicrocontrollerInputModule.csv, BOM-RGB-Panel.csv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]
2025-01-31 PCBway Shared Projects setup
    [MicrocontrollerInputModule.kicad_pcb, MicrocontrollerInputModule.kicad_pcb_bom.csv, MicrocontrollerInputModule.kicad_pcb_positions.csv]
